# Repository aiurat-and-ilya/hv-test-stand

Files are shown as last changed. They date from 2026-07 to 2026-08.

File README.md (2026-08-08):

# Лабораторный стенд для испытания высоковольтных радиоэлементов (HV Test Stand)

Специализированный лабораторный прибор для проведения комплексных испытаний высоковольтных полупроводниковых компонентов и диэлектрических материалов (измерение токов утечки, определение напряжения пробоя). 

Проект охватывает полный цикл разработки устройства: от проектирования схемы и симуляции физических процессов до конструирования корпуса, подготовки файлов производства и натурных испытаний готового стенда.

Разработчики: **[aiurat](https://github.com/aiurat)** и **[ilyakorni](https://github.com/ilyakorni)**.

---

## 1. Схемотехника и трассировка платы (EasyEDA)

Электронный узел устройства спроектирован в среде **EasyEDA**:
* **Схема:** Импульсный повышающий преобразователь (Boost Converter) на базе ШИМ-контроллера **TL494 (DA2)** и драйвера затвора **IR2302 (DA1)**. Первичное питание осуществляется через интерфейс USB Type-C (**X1**) с триггером быстрой зарядки **CH224K (DD1)**, запрашивающим профиль питания 12 В (до 2 А).
* **Плата:** Двухслойная печатная плата (FR-4) со встроенным планарным радиатором (медными полигонами без паяльной маски) для пассивного охлаждения силового ключа **VT2 (IRF640)**.

<p align="center">
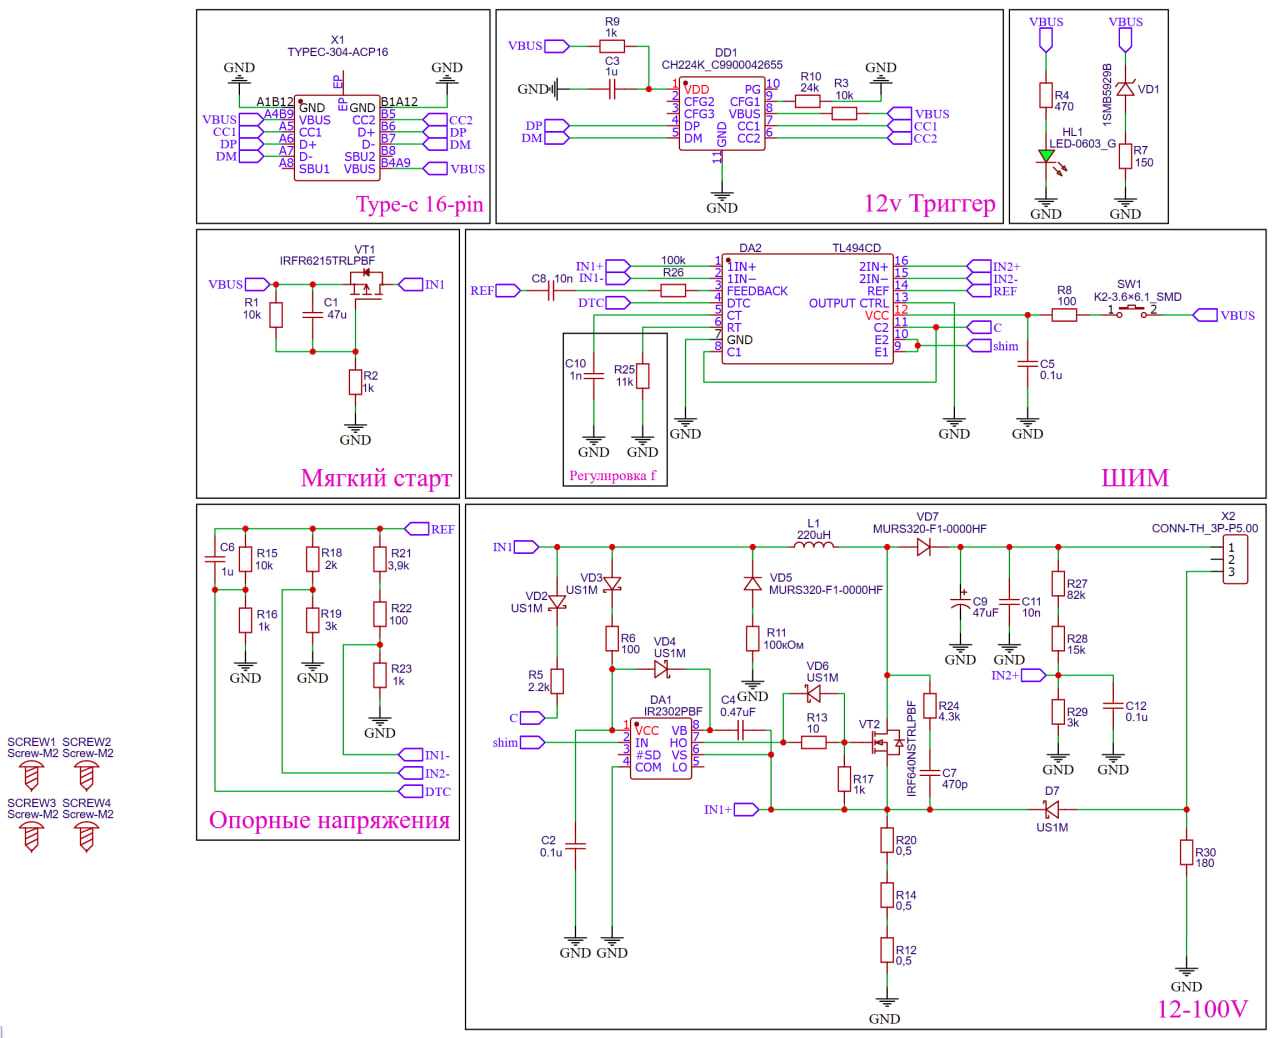
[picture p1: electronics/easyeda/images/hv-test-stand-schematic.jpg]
Принципиальная схема стенда
  
</p>

<p align="center">
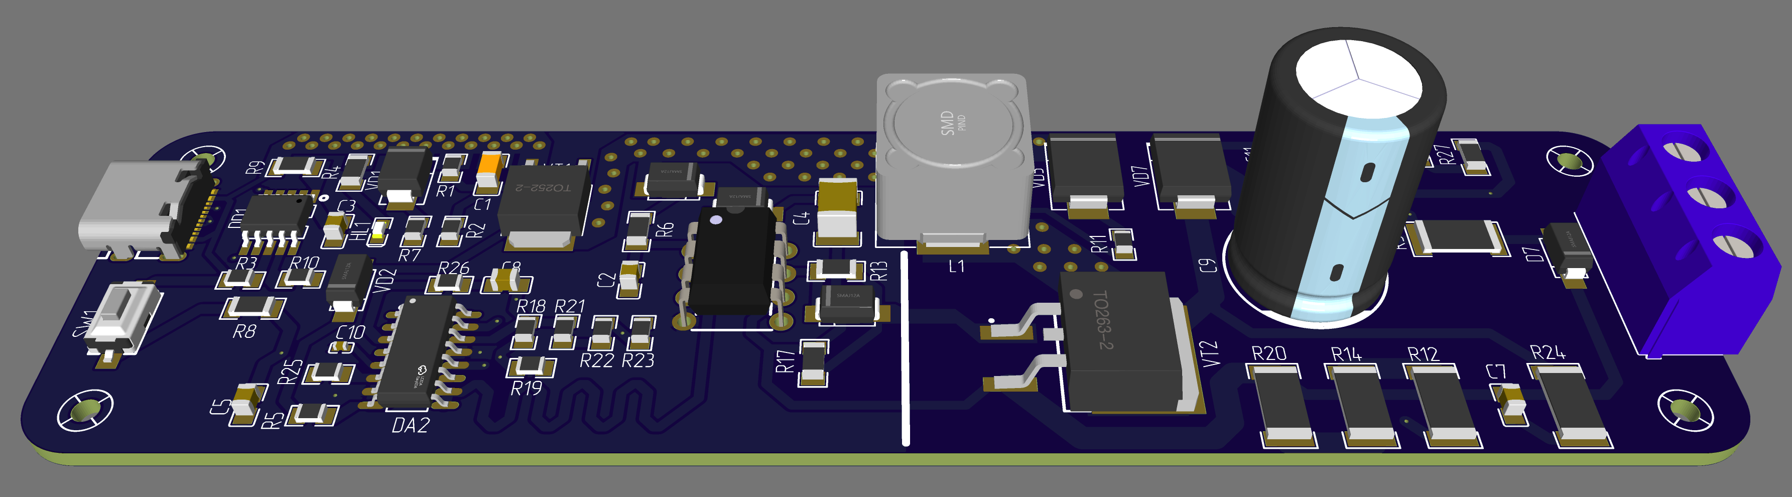
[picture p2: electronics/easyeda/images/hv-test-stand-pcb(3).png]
3D-модель печатной платы
  
</p>

---

## 2. Симуляция физических процессов

Перед отправкой платы в производство было проведено компьютерное моделирование ключевых узлов устройства:

### Тепловое моделирование планарного радиатора (CST Studio Suite)
Для качественной оценки эффективности охлаждающего медного полигона была проведена тепловая симуляция в 3 итерации:
1. **Итерация 1 (Базовая):** Упрощенный расчет на пустом текстолите для оценки векторов распространения тепла.
2. **Итерация 2 (Контрольная):** Моделирование платы с компонентами без физического контакта полигона радиатора с платой в расчетной сетке. Это позволило зафиксировать характерный критический перегрев в одной точке при отсутствии теплоотвода.
3. **Итерация 3 (Финальная):** Тепловой контакт был настроен. Добавлены точки нагрева в зоне без радиатора (3 резистора). Симуляция наглядно подтвердила, что в зоне без радиатора образуется сильный перегрев, тогда как планарный медный полигон успешно распределяет и уводит тепло по плате.

<p align="center">
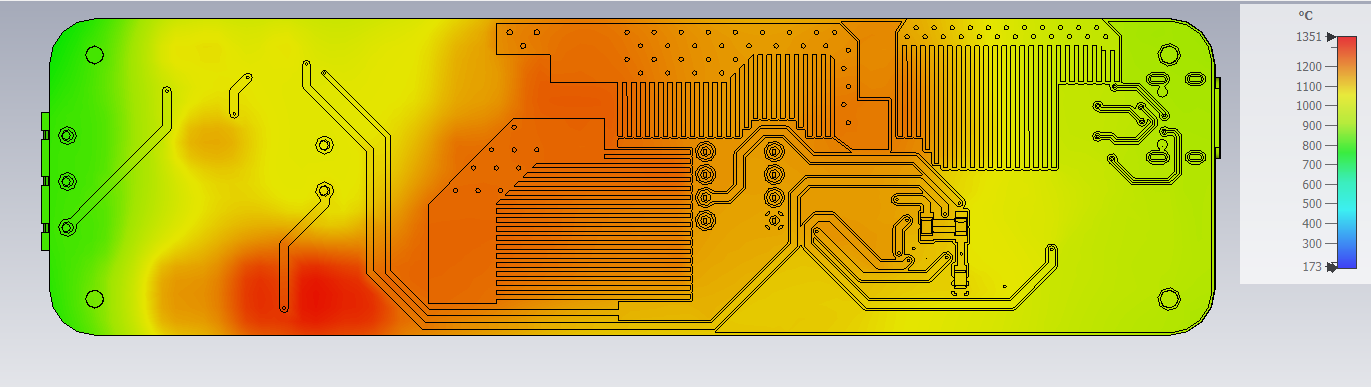
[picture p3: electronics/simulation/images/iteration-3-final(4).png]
Тепловое моделирование в CST Studio Suite
  
</p>

### Моделирование мягкого старта (Micro-Cap)
Проведено моделирование переходных процессов (*Transient Analysis*) узла мягкого старта на транзисторе **VT1**. Моделирование подтвердило плавное нарастание напряжения на нагрузке и ограничение бросков зарядного тока конденсаторов фильтра, что защищает первичный блок питания от перегрузки при старте.

<p align="center">
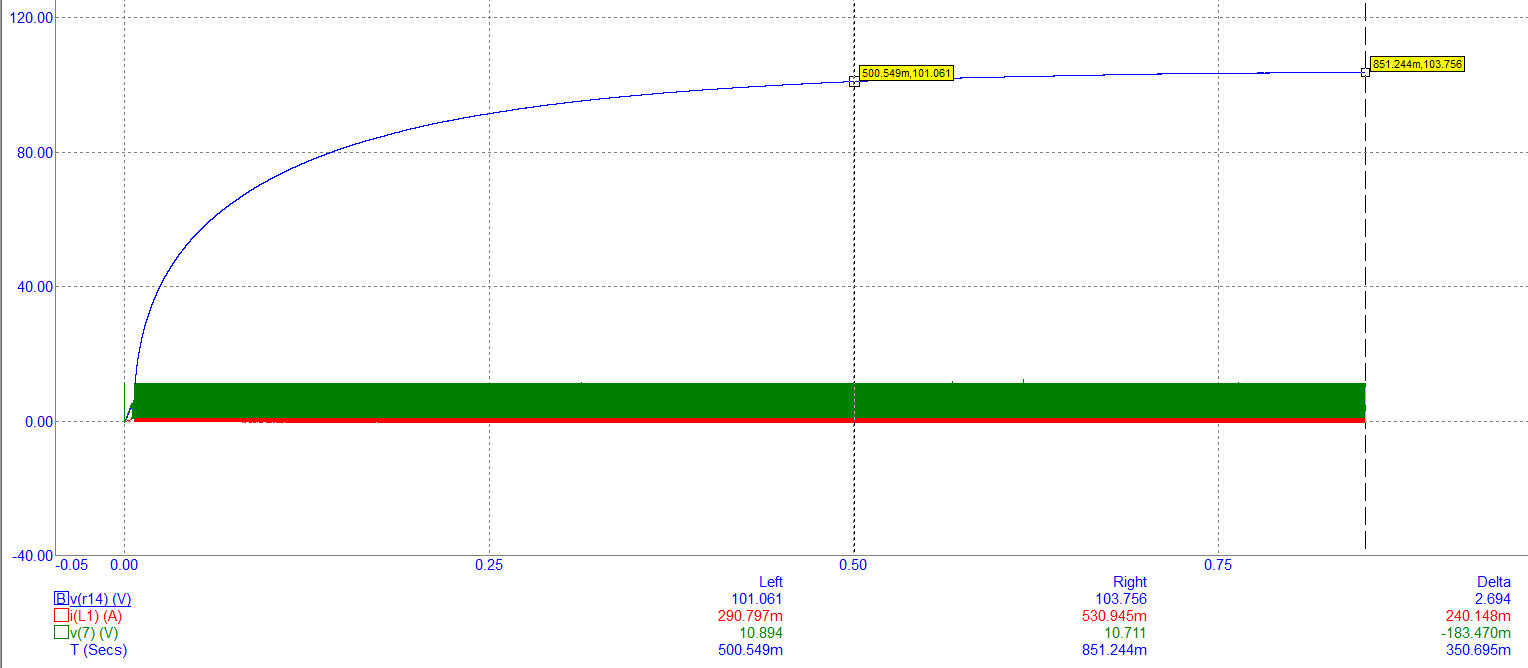
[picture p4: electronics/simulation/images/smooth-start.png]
Симуляция мягкого старта в Micro-Cap
  
</p>

---

## 3. Конструирование корпуса (КОМПАС-3D)

В системе **КОМПАС-3D** спроектирован защитный корпус прибора:
* Конструкция корпуса разделена на отдельные функциональные части (основание, крышка, панели) для удобства 3D-печати.
* В общую механическую сборку (`.a3d`) была импортирована STEP-модель печатной платы (`hv-test-stand-pcb.step`) для контроля соосности разъемов, клемм, кнопок и крепежных отверстий.

---

## 4. Производство и финальные испытания

По подготовленной документации (Gerber-файлы, BOM-таблица, технологическая маршрутная карта) плата была успешно изготовлена, смонтирована и протестирована:
* Проведены замеры выходного напряжения с помощью мультиметра.
* Зафиксирована стабильная работа преобразователя и генерация выходного напряжения **99.6 В** при питании от интерфейса USB-C.

<p align="center">
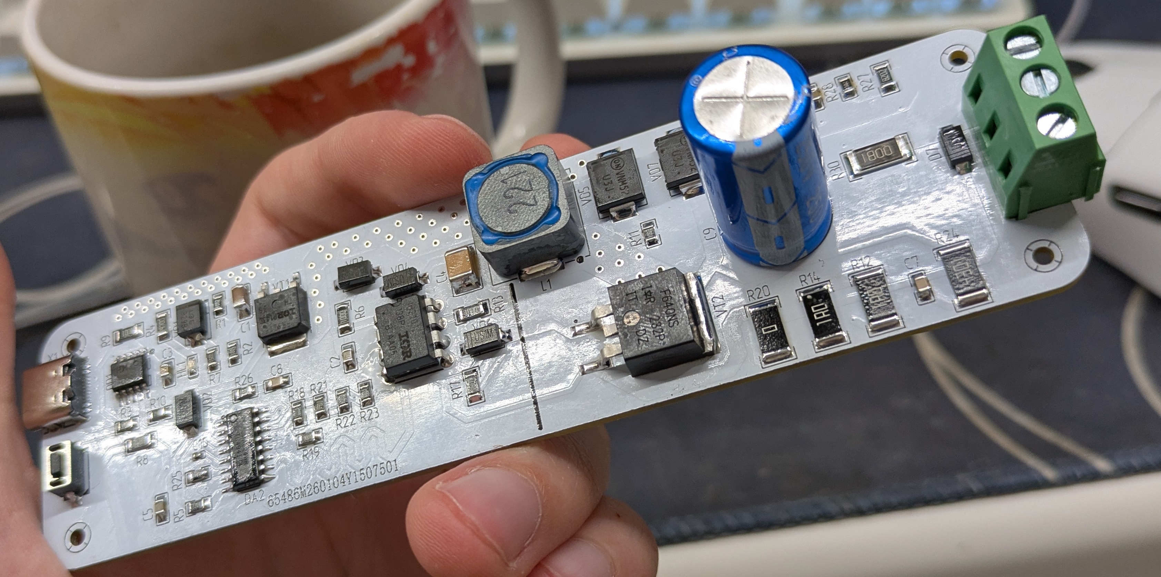
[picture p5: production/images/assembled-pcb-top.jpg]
Собранная плата
  
</p>

<p align="center">
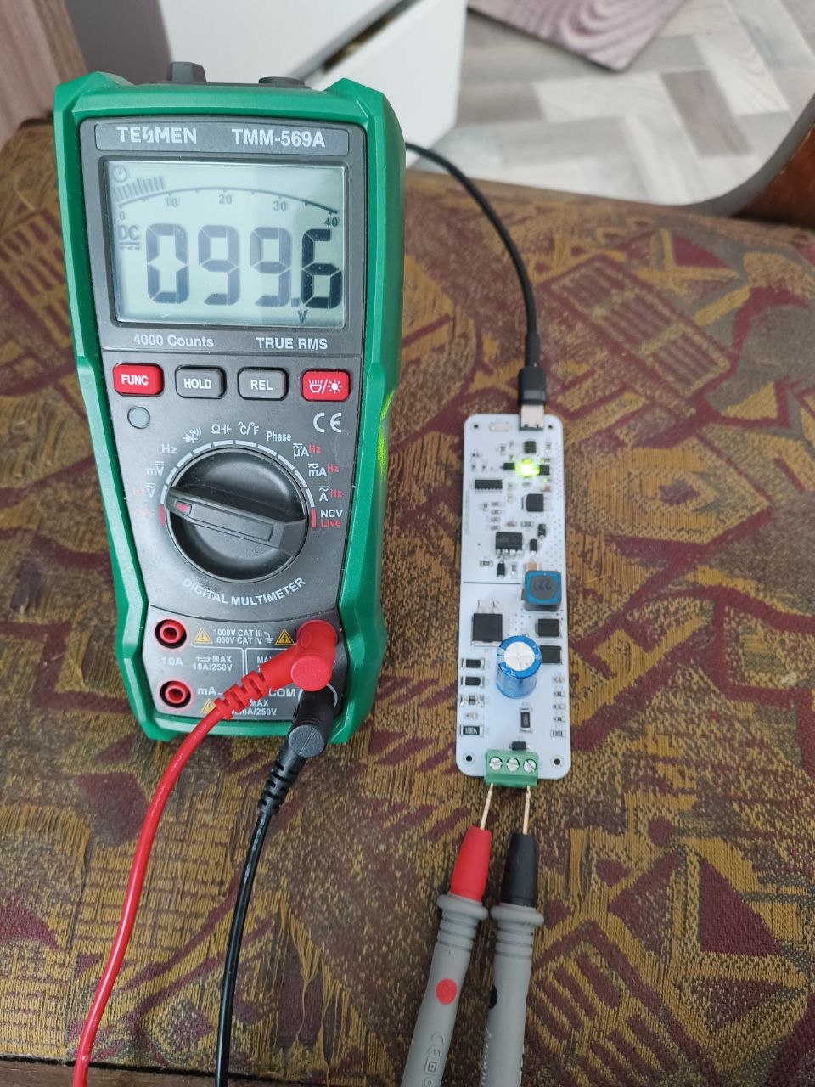
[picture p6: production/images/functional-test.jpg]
Тест выходного напряжения
  
</p>

---

## 5. Навигация по репозиторию

* 🔌 **[Электроника](./electronics/)** — принципиальная схема и печатная плата в EasyEDA.
* 📈 **[Симуляции](./electronics/simulation/)** — подробные отчеты и файлы тепловых расчетов (CST) и мягкого старта (Micro-Cap).
* ⚙️ **[Механика](./mechanical/)** — 3D-модели корпуса (КОМПАС-3D) и STEP-файл платы.
* 🛠️ **[Производство](./production/)** — Gerber-файлы, чертежи PDF, спецификация (BOM) со ссылками и фотографии готового прибора.
* 📄 **[Документация](./docs/)** — подробное [описание работы схемы](./docs/README.md).

## Лицензия

Copyright (c) 2026 Айрат Ялалетдинов, Илья Корнилов

Этот исходный документ описывает открытое аппаратное обеспечение (Open Hardware) и распространяется под лицензией CERN-OHL-P v2. 
Вы можете распространять и изменять этот исходный документ, а также производить на его основе продукты в соответствии с 
условиями лицензии CERN-OHL-P v2 (https://cern.ch/cern-ohl).

Этот исходный документ распространяется БЕЗ КАКИХ-ЛИБО ЯВНЫХ ИЛИ ПОДРАЗУМЕВАЕМЫХ ГАРАНТИЙ, 
ВКЛЮЧАЯ ГАРАНТИИ ТОВАРНОЙ ПРИГОДНОСТИ, УДОВЛЕТВОРИТЕЛЬНОГО КАЧЕСТВА ИЛИ СООТВЕТСТВИЯ 
КОНКРЕТНЫМ ЦЕЛЯМ. Пожалуйста, ознакомьтесь с условиями CERN-OHL-P v2 для получения подробной информации.

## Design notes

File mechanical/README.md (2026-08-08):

# Механическая часть (КОМПАС-3D)

В этом разделе находятся файлы конструкции корпуса прибора, разработанные в системе **КОМПАС-3D**.

### Структура папки:

* 📁 **[enclosure](./enclosure/)** — исходные 3D-модели:
  * Общая сборка корпуса (`.a3d`).
  * Детали корпуса для печати/изготовления (`.m3d`).
  * Фурнитура (модели винтов, тактовых кнопок).
* 📁 **[images](./images/)** — скриншоты готовых 3D-моделей и деталей корпуса.
* 📁 **[drawings](./drawings/)** — чертежи деталей и сборочные единицы в формате `.cdw`.
* 📄 **[pcb.step](./pcb.step)** — 3D-модель печатной платы (STEP), импортированная для сопряжения и контроля зазоров в общей сборке.

---

## 3D-визуализация корпуса прибора

<p align="center">
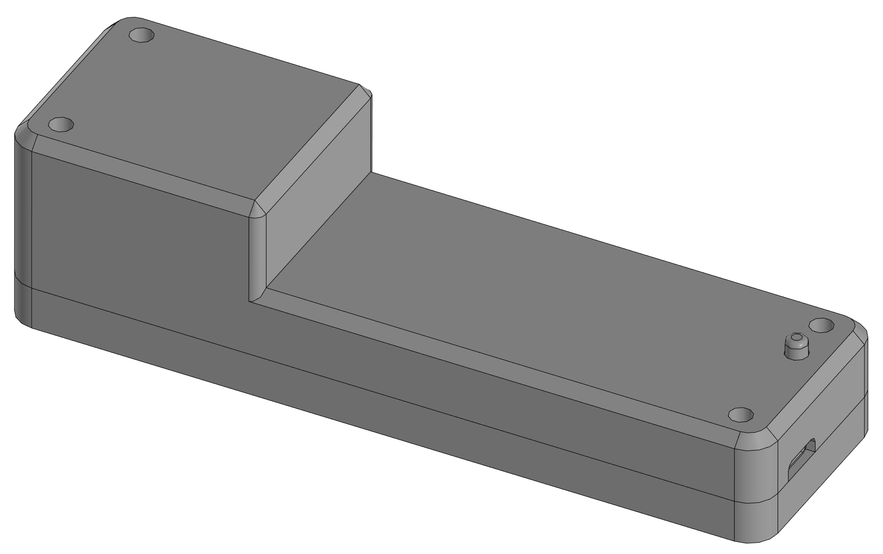
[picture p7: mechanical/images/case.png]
Общая сборка корпуса стенда
  
  <br/><br/>
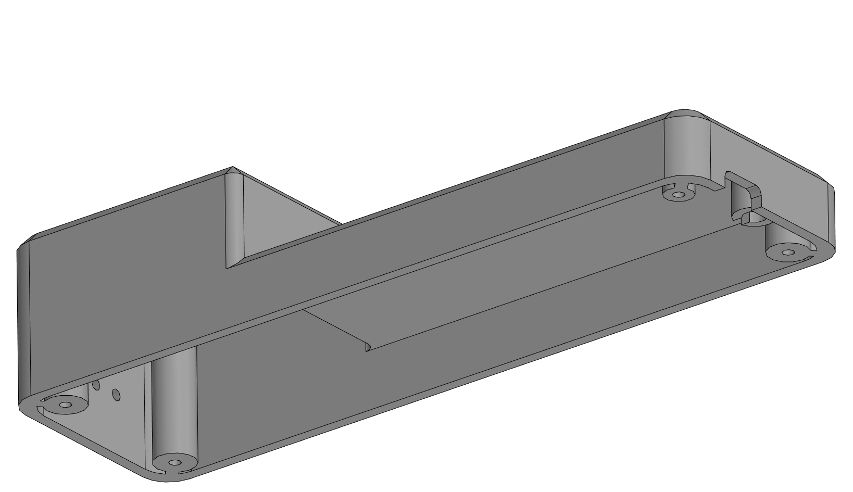
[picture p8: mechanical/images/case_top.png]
Верхняя крышка корпуса (Top Cover)
  
  <br/><br/>
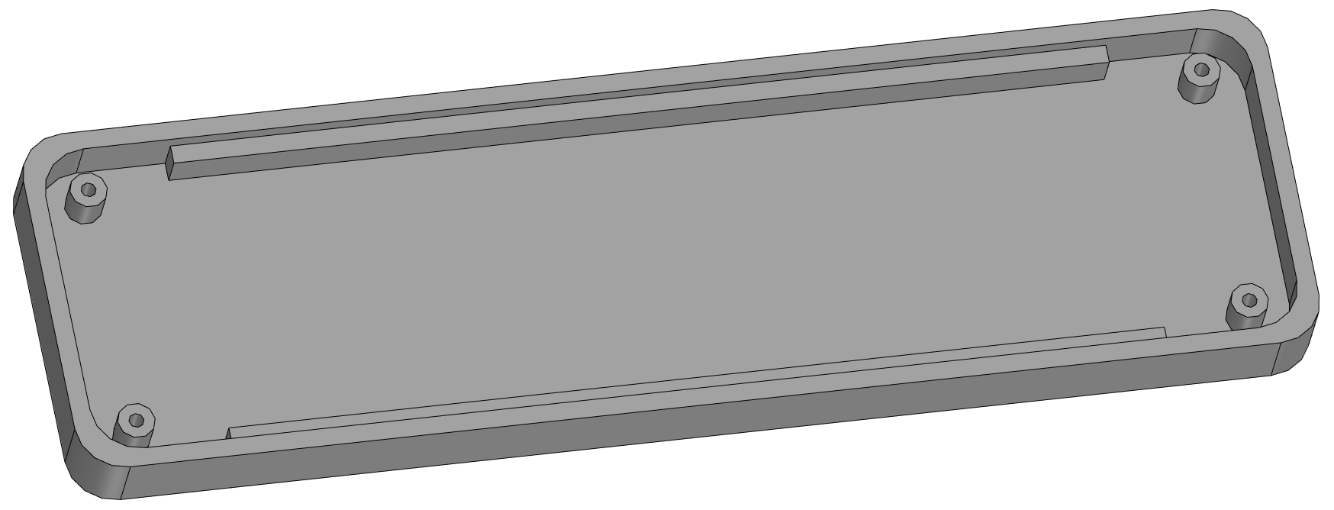
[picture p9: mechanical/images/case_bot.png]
Основание корпуса (Bottom Base)
  
</p>

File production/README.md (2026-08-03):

# Файлы для производства (Production)

В этом разделе собраны финальные файлы, необходимые для заказа печатной платы, закупки компонентов и сборки устройства.

### Содержимое папки:

* 📁 **[gerber](./gerber/)** — Gerber-файлы (проект платы, подготовленный для отправки на производство).
* 📁 **[drawings](./drawings/)** — сборочные и габаритные чертежи деталей в формате `PDF` для быстрого просмотра и печати.
* 📁 **[images](./images/)** — фотографии изготовленной платы (без компонентов и в сборе), а также тест замера выходного напряжения.
* 📄 **[bom.xlsx](./bom.xlsx)** — перечень элементов (BOM) со спецификациями и ссылками на компоненты в магазине «Чип и Дип» *(примечание: некоторые внешние ссылки со временем могли стать неактуальными)*.

---

## Фотографии изготовленной печатной платы и тестирования

### 1. Печатная плата без компонентов
<p align="center">
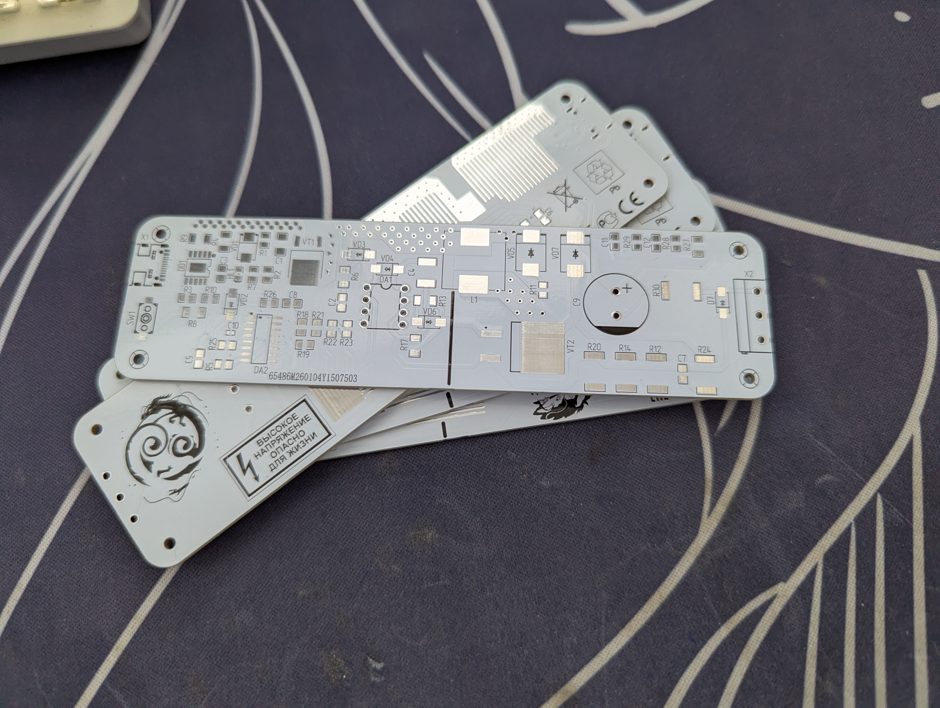
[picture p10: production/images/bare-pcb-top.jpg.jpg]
Голая печатная плата - Вид сверху
  
  <br/><br/>
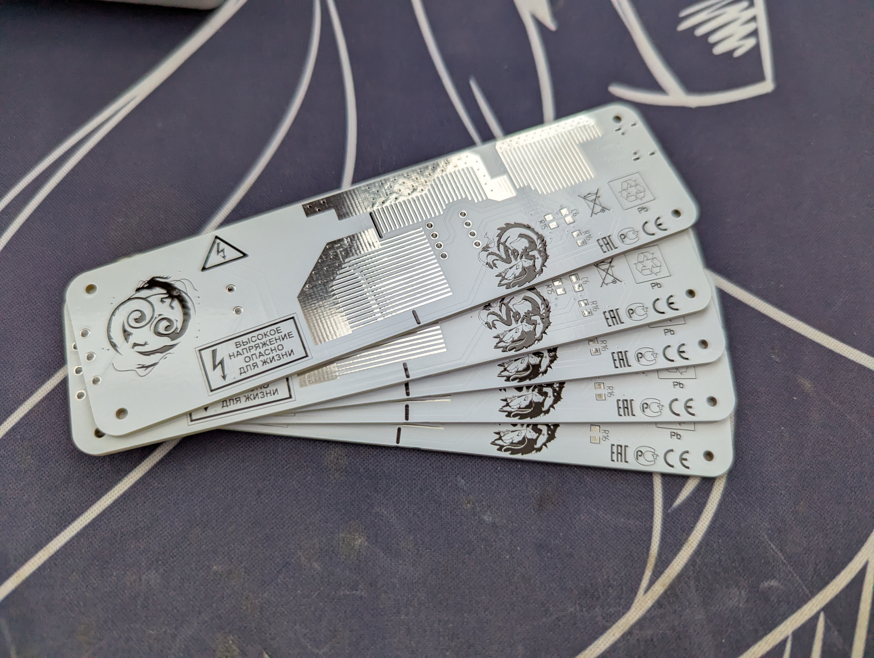
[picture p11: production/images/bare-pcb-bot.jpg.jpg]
Голая печатная плата - Вид снизу
  
</p>

---

### 2. Печатная плата в сборе
<p align="center">
  Смонтированная печатная плата - Вид сверху
  <br/><br/>
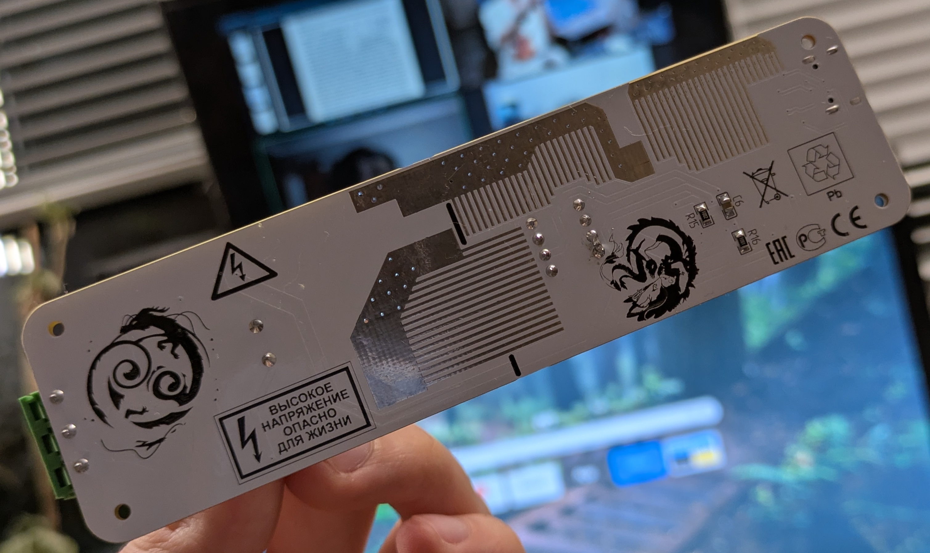
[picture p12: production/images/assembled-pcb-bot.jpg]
Смонтированная печатная плата - Вид снизу
  
</p>

---

### 3. Функциональный тест
<p align="center">
  Проверка выходного напряжения преобразователя
</p>

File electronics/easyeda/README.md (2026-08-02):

# Проектирование схемы и печатной платы (EasyEDA)

Разработка электрической принципиальной схемы и топологии печатной платы (PCB) лабораторного стенда выполнена в среде проектирования **EasyEDA**. 

В данном подразделе представлены графические материалы проекта: принципиальная схема, а также двухмерная и трехмерная визуализация печатной платы.

---

## 1. Схема электрическая принципиальная

Схема разработана с учетом требований к компоновке импульсных повышающих преобразователей. Логические цепи управления (ШИМ-контроллер TL494, драйвер IR2302) развязаны и защищены от помех со стороны силовой части.

<p align="center">
  Принципиальная схема стенда
</p>

---

## 2. Топология печатной платы (2D-вид)

Печатная плата выполнена на двухслойном фольгированном стеклотекстолите (FR-4). Трассировка силовых дорожек сделана максимально широкой для минимизации сопротивления и нагрева. Также на плате сформированы свободные от паяльной маски медные полигоны, выполняющие роль планарного радиатора для пассивного охлаждения силовых элементов.

*Ниже представлены скриншоты проводящего рисунка платы без установленных компонентов (верхний и нижний слои):*

<p align="center">
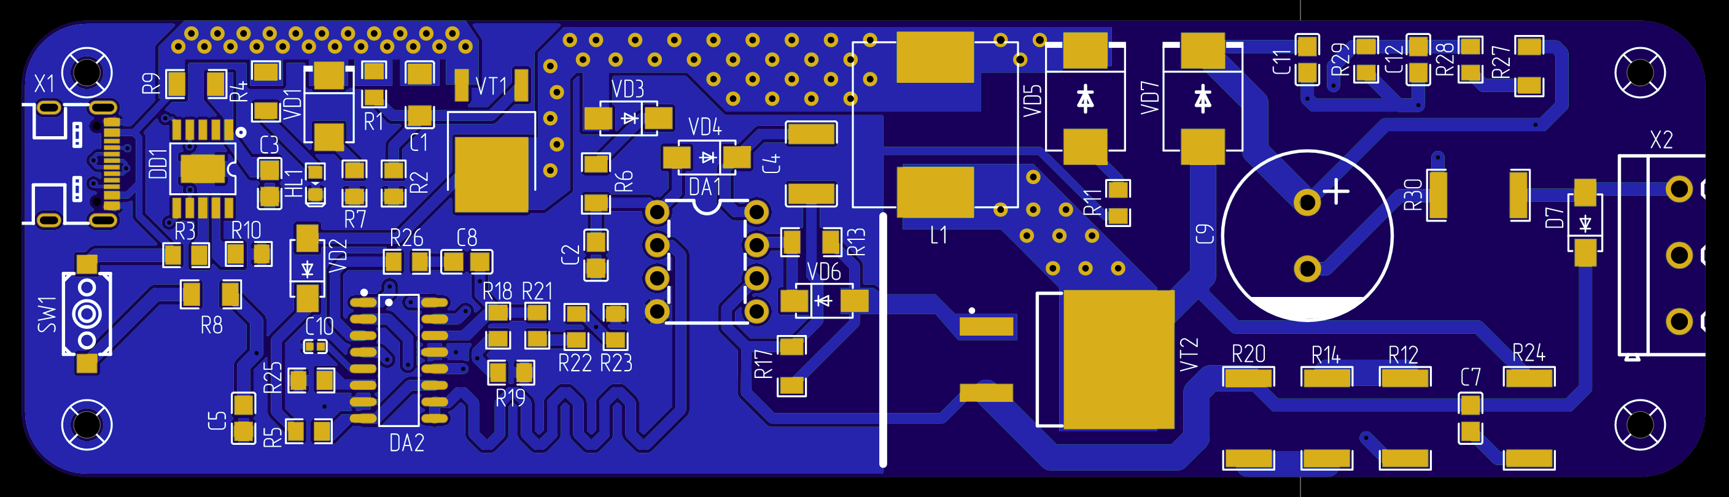
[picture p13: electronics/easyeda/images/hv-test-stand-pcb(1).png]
Топология печатной платы - Верхний слой (Top Layer)
  
  <br/><br/>
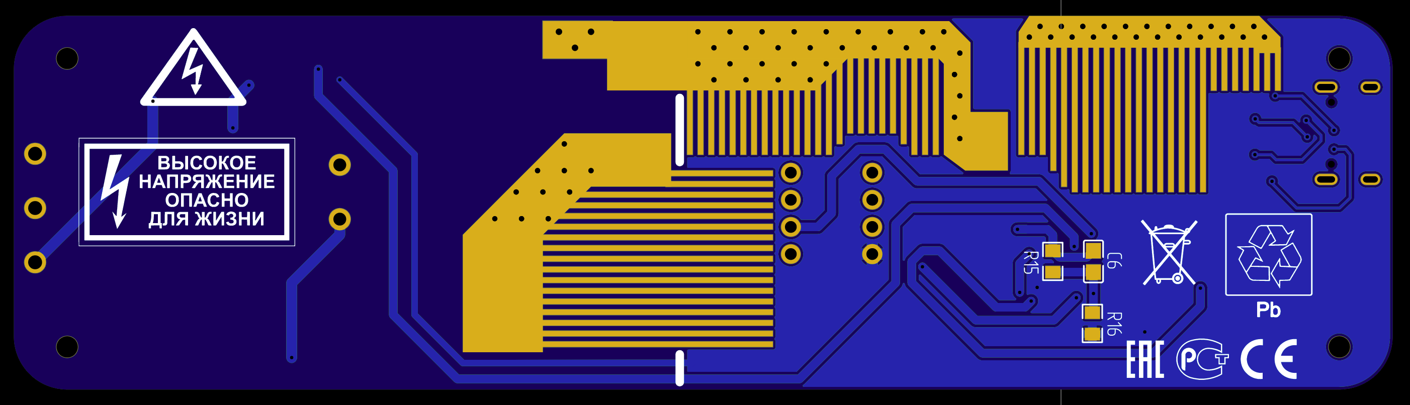
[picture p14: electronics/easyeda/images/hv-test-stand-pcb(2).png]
Топология печатной платы - Нижний слой (Bottom Layer)
  
</p>

---

## 3. Трехмерная визуализация платы (3D-вид)

Для проверки механической совместимости компонентов и оценки плотности компоновки элементов была построена трехмерная модель печатной платы в сборе с корпусами радиодеталей.

*Ниже представлены 3D-рендеры готовой платы (с установленными компонентами):*

<p align="center">
  3D-визуализация платы - Вид сверху
  <br/><br/>
  3D-визуализация платы - Вид снизу
</p>

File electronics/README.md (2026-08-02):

# Электроника (Electronics)

Схемотехника, трассировка печатной платы в **EasyEDA** и симуляция физических процессов прибора.

### Структура папки:

* 📁 **[easyeda](./easyeda/)** — исходные файлы схемы и платы в формате проекта EasyEDA.
* 📁 **[simulation](./simulation/)** — тепловой анализ планарного радиатора в CST Studio Suite и симуляция переходных процессов в Micro-Cap.

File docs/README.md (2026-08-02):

# Описание работы электрической принципиальной схемы стенда

Разработанное устройство представляет собой специализированный лабораторный стенд, предназначенный для проведения комплексных испытаний высоковольтных полупроводниковых компонентов и материалов. 

### Основные инженерно-технические задачи стенда:
* **Измерение токов утечки** (обратных токов) радиоэлементов при воздействии высоких напряжений с использованием внешнего измерительного прибора (микроамперметра).
* **Проверка диэлектрической прочности** и определение напряжения пробоя активных и пассивных компонентов.
* **Обеспечение питанием маломощных узлов** и приборов, требующих для работы высокого потенциала.

Устройство выполнено на базе импульсного повышающего преобразователя напряжения с развитой системой обратных связей по току и напряжению, что обеспечивает стабильность выходных характеристик и безопасность эксплуатации.

---

## 1. Входной узел и система питания

Питание стенда осуществляется через современный интерфейс USB Type-C (разъем **X1**). 

* **Контроллер-триггер DD1 (CH224K):** Введен в схему для реализации возможности получения повышенной мощности от современных зарядных устройств. Данная микросхема поддерживает протоколы быстрой зарядки, такие как *USB Power Delivery (PD)* и *Quick Charge (QC)*. Использование контроллера **DD1** позволяет согласовать с источником питания выходное напряжение **12 В при токе до 2 А**, что значительно расширяет энергетический бюджет устройства по сравнению со стандартными 5 В.
* **Стабилитрон VD1 и резистор R7:** Установлены в цепи питания для защиты низковольтной логической части от случайных скачков напряжения. Резистор **R7** стабилизирует рабочую точку стабилитрона.
* **Светодиодный индикатор HL1:** Обеспечивает визуальный контроль подачи первичного напряжения. Включен через токоограничивающий резистор **R4**.

---

## 2. Узел мягкого старта и безопасность

Важной особенностью конструкции является наличие системы «мягкого старта» первичных цепей и аппаратного контроля безопасности.

* **Система «мягкого старта» на полевом транзисторе VT1:**
  * **Принцип работы:** При подаче питания цепи смещения в затворе **VT1** обеспечивают постепенное открытие канала сток-исток. Плавное изменение поперечного сечения канала приводит к постепенному снижению сопротивления участка цепи, что ограничивает производную тока и исключает броски тока при зарядке емкостей фильтра.
* **Тактовая кнопка SW1:** Включение высоковольтной части устройства жестко привязано к нажатию кнопки **SW1**. Это исключает наличие высокого потенциала на выходных клеммах **X2** в режиме ожидания, обеспечивая безопасность оператора.

---

## 3. ШИМ-управление на базе TL494

Центральным управляющим звеном преобразователя является специализированная микросхема **DA2 (TL494)** — классический двухтактный ШИМ-контроллер, работающий в данном случае в схеме однотактного управления силовым ключом.

### Функциональная обвязка TL494:

1. **Цепь задания частоты:** Резистор **R25** и конденсатор **C10** определяют частоту встроенного осциллятора, задавая тем самым стабильную частоту коммутации силового ключа.
2. **Регулировка мертвого времени (DTC):** Элементы **R15**, **R16**, **C6**, подключенные к выводу *DTC (Dead Time Control)*, реализуют дополнительный уровень мягкого запуска непосредственно для ШИМ-сигнала, предотвращая резкие выбросы напряжения при старте генерации.
3. **Система обратных связей:**
   * **Контур стабилизации напряжения:** Делитель на прецизионных резисторах **R27**, **R28**, **R29** снимает сигнал с выхода устройства и подает его на встроенный усилитель ошибки **DA2** (через опорные цепи **R18**, **R19**), непрерывно поддерживая заданный уровень выходного напряжения.
   * **Контур защиты по току:** Группа низкоомных шунтов **R12**, **R14**, **R20** в истоковой цепи силового ключа и опорная сеть **R21**, **R22**, **R23** обеспечивают мониторинг мгновенного тока через транзистор.
   * **Защита от короткого замыкания:** Цепь **R30**, **VD8** обеспечивает дополнительный контроль выходного тока, предохраняя устройство от выхода из строя при аварийных режимах (КЗ) на выходных клеммах **X2**.

---

## 4. Силовой каскад и драйвер ключа

* **Драйвер затвора DA1 (IR2302PBF):** Применен для эффективного управления мощным полевым транзистором. Данная микросхема обеспечивает необходимый импульсный ток для быстрой зарядки и разрядки входной емкости затвора силового транзистора **VT2**. Это критически важно для минимизации динамических потерь на ключе и предотвращения работы транзистора в линейном (активном) режиме, сопровождающемся чрезмерным тепловыделением.
* **Силовой ключ VT2 (IRF640):** Мощный МОП-транзистор (MOSFET), обладающий высокой мощностью рассеивания и достаточным напряжением сток-исток для обеспечения стабильной и надежной работы повышающего преобразователя.

### Элементы оптимизации силовой цепи:
* **Дроссель L1:** Является основным накопителем энергии преобразователя. В фазе открытого состояния ключа **VT2** энергия запасается в магнитном поле индуктивности.
* **Снабберная цепь R24, C7:** Образуют RC-снаббер, включенный параллельно силовому ключу. Он поглощает энергию паразитных колебаний и подавляет высокочастотные гармоники («звон»), возникающие в моменты коммутации индуктивности дросселя.
* **Цепь разрядки L1 (VD5, R11):** Диод **VD5** и резистор **R11** способствуют контролируемой разрядке накопленной энергии в моменты закрытия ключа, защищая компоненты схемы от высоковольтного пробоя импульсами самоиндукции.

---

## 5. Выпрямление и фильтрация выходного напряжения

На выходе преобразователя установлен быстродействующий высокочастотный диод **VD7**, выполняющий функцию выпрямления импульсного напряжения. 

Для получения чистого постоянного напряжения на клеммах применяется комбинированная многоступенчатая система фильтрации:
* **Электролитический конденсатор C9:** Обладает большой емкостью и предназначен для эффективного сглаживания низкочастотных пульсаций напряжения.
* **Керамический конденсатор C11:** Благодаря сверхнизкой собственной индуктивности (*ESL*), эффективно подавляет высокочастотные помехи и импульсные всплески в цепи, с которыми физически не справляется электролитический конденсатор.
* **Конденсатор фильтрации измерительной цепи C12:** Обеспечивает финальную фильтрацию в цепи измерения, стабилизируя показания тока и напряжения при подключении внешнего микроамперметра к контакту 2 разъема **X2**.

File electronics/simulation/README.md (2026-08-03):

# Моделирование и симуляция физических процессов

В данном разделе представлены результаты теплового моделирования охлаждающей способности планарного радиатора в среде **CST Studio Suite**, а также схемотехнического анализа узла мягкого старта в программе **Micro-Cap**.

---

## 1. Тепловой анализ планарного радиатора (CST Studio Suite)

**Цель исследования:** Качественная оценка эффективности работы планарного радиатора (медного полигона печатной платы) и визуализация путей распределения тепла по плате.

*Примечание: Так как точные значения тепловыделения реальных компонентов на этапе проектирования могут варьироваться, тепловая мощность в моделях задавалась с избыточным запасом. Абсолютные значения температур в симуляциях носят номинальный характер и служат для демонстрации градиентов теплоотвода.*

### Итерация 1: Упрощенная базовая модель
На первом этапе была подготовлена упрощенная модель, состоящая только из текстолитового основания и медных проводников, без учета корпусов радиокомпонентов.
* **Методика:** В качестве источника тепла в CST Studio Suite был создан условный твердотельный объект (кубик), расположенный непосредственно в зоне планарного радиатора.
* **Результат:** Зафиксирован нагрев в самой горячей точке до **41.3 °C**. Модель позволила оценить базовые направления растекания тепла.
* **Выявленные недостатки:** Для реалистичного анализа необходимо использовать полную 3D-сборку платы с компонентами и задать несколько распределенных точек нагрева.

<p align="center">
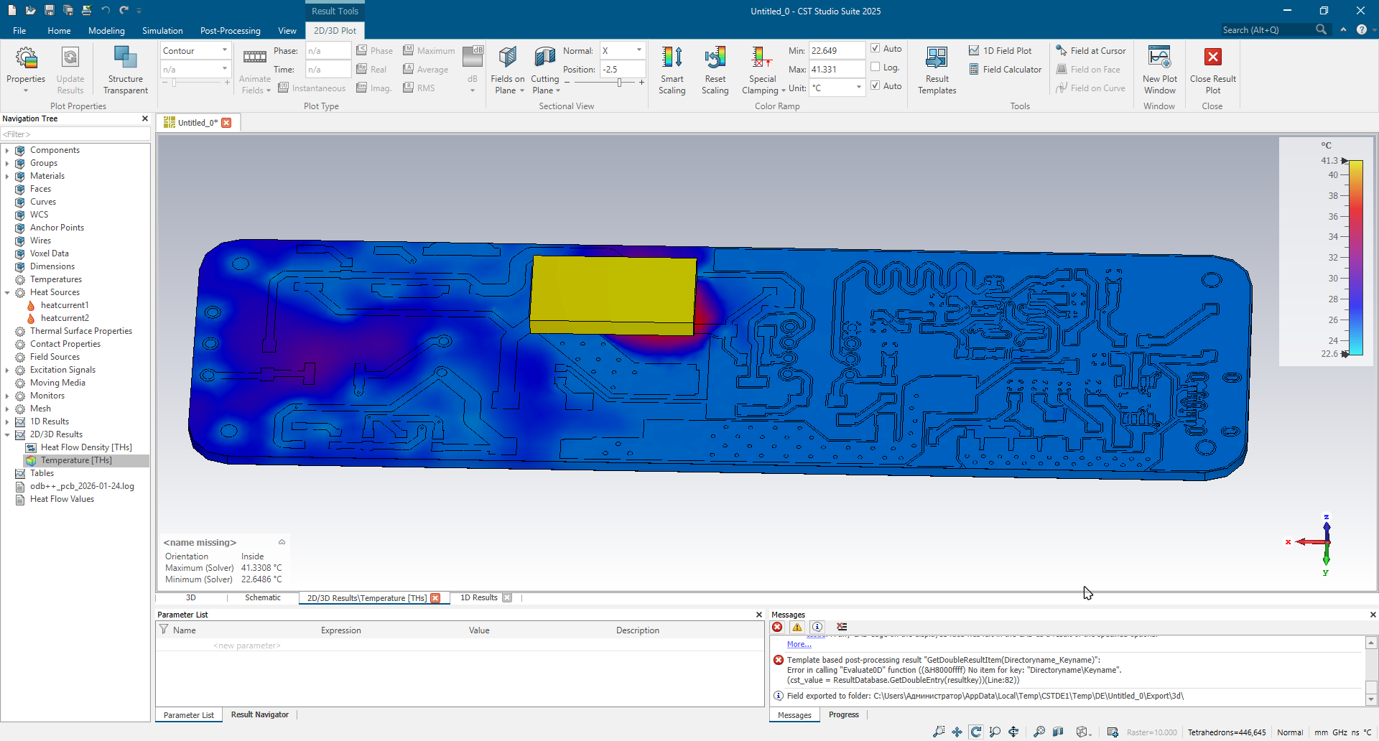
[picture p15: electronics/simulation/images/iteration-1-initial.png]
Итерация 1 - Базовая модель
  
</p>

---

### Итерация 2: Модель с компонентами (без теплового контакта)
На этом этапе была задействована детализированная 3D-модель платы со всеми установленными радиоэлементами.
* **Методика:** Выделены 3 характерные точки нагрева на корпусах компонентов, расположенных в зоне планарного радиатора. На них была подана тепловая нагрузка.
* **Результат:** Зафиксирован сильный локальный перегрев (пиковое значение **590 °C**) из-за завышенной мощности источников.
* **Выявленные особенности и дефекты:** 
  При анализе модели обнаружилось, что медный полигон радиатора и подложка печатной платы физически не соприкасались в расчетной сетке. Данная ошибка позволила использовать итерацию в качестве «контрольной группы»: на тепловой карте отчетливо видно, как тепло концентрируется исключительно в точках нагрева и не уходит в плату из-за отсутствия теплового контакта.
* **План действий:** Обеспечить корректное механическое и тепловое сопряжение проводников с платой для сравнения результатов.

<p align="center">
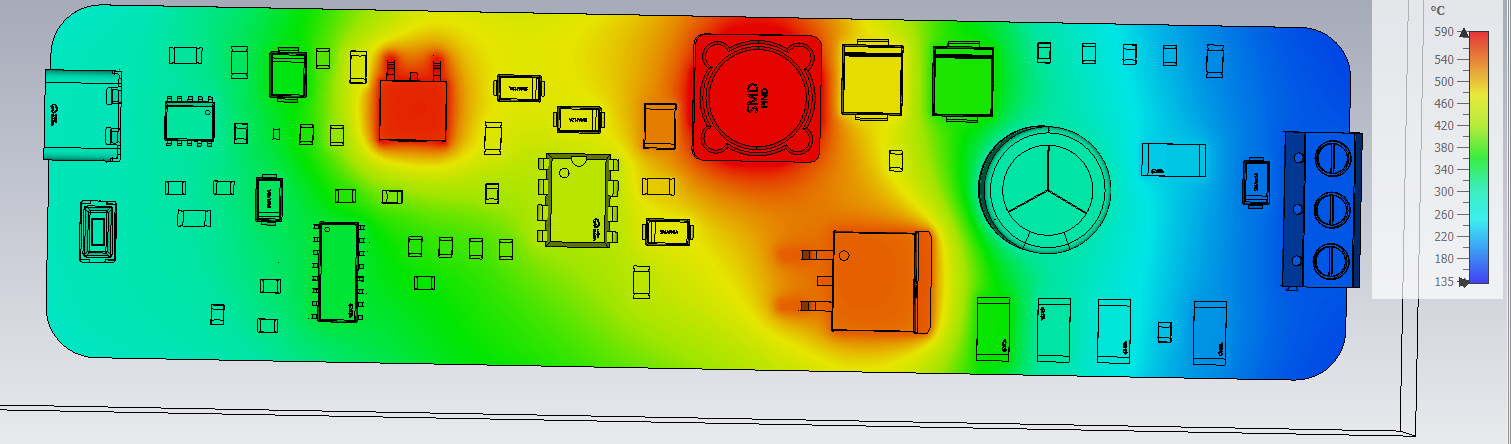
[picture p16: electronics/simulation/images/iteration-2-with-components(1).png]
Итерация 2 - Общий вид
  
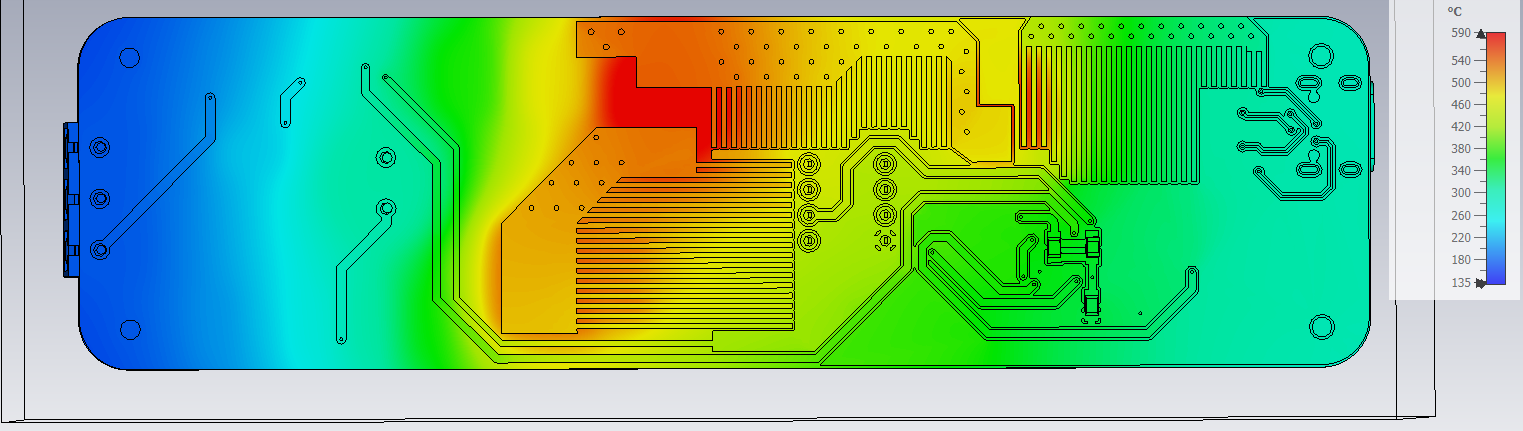
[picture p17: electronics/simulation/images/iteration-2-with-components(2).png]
Итерация 2 - Тепловая карта
  
</p>

---

### Итерация 3: Финальная модель (с тепловым контактом)
В финальной версии модели были устранены все геометрические несоответствия и добавлены дополнительные тепловые источники для сравнительного анализа.
* **Методика:** 
  * Настроено корректное сопряжение (тепловой контакт) радиаторов с поверхностью печатной платы.
  * Добавлены новые точки нагрева, в том числе в области платы, где планарный радиатор отсутствует (группа из 3 рядом стоящих резисторов).
* **Результат:** 
  Из-за улучшения теплопередачи и добавления источников пиковая температура на модели составила **1351 °C** (номинальное значение). Симуляция наглядно продемонстрировала разницу процессов:
  * В зоне трех резисторов (без радиатора) наблюдается критическая локальная точка перегрева с резким градиентом.
  * В зонах компонентов, сопряженных с медными полигонами, тепло эффективно распределяется по площади радиатора и рассеивается в объеме платы.
* **Вывод:** Тестовое моделирование завершено, работоспособность и высокая эффективность планарного радиатора успешно подтверждены качественным анализом.

#### Тепловые карты проводящего рисунка (медных слоев):
<p align="center">
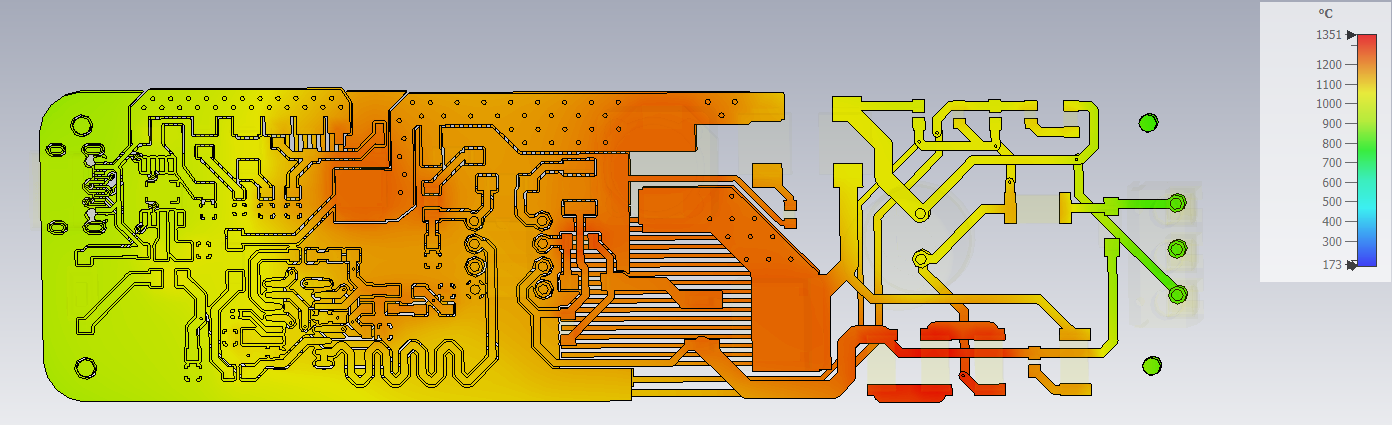
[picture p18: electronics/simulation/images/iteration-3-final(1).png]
Итерация 3 - Медные слои 1
  
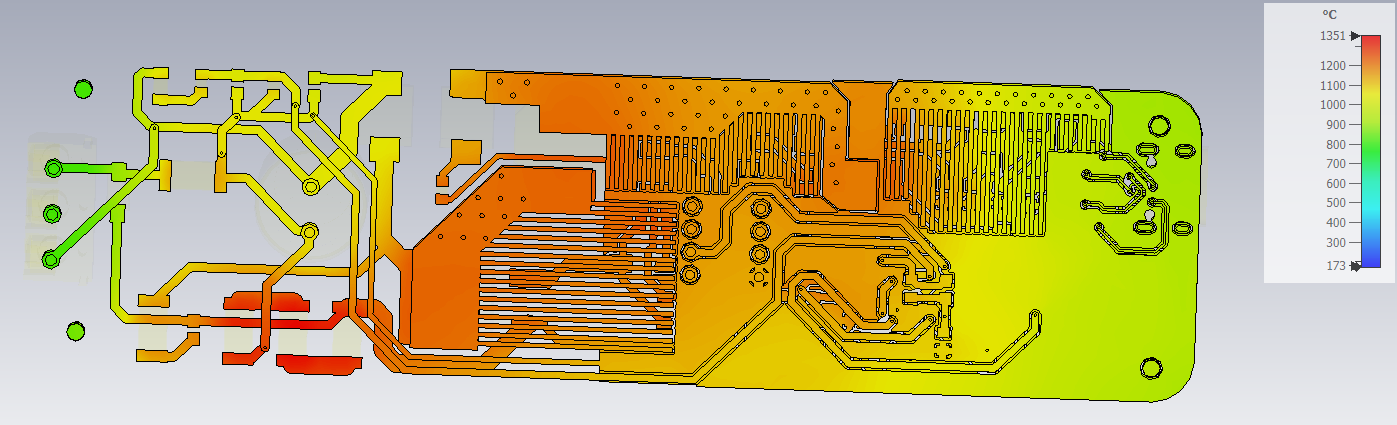
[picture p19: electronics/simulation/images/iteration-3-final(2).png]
Итерация 3 - Медные слои 2
  
</p>

#### Тепловые карты всей платы в сборе:
<p align="center">
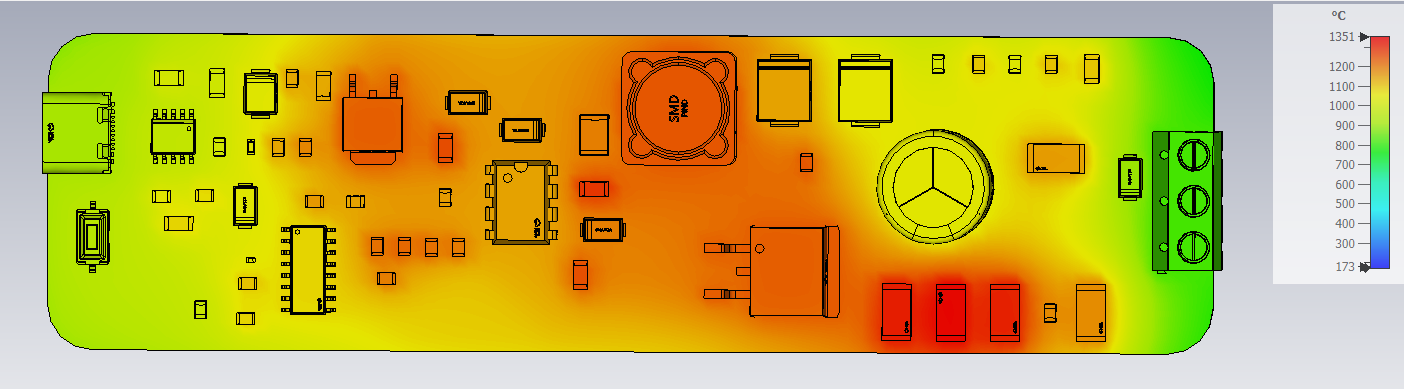
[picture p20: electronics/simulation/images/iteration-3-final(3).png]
Итерация 3 - Сборка платы 1
  
  Итерация 3 - Сборка платы 2
</p>

---

## 2. Схемотехническое моделирование мягкого старта (Micro-Cap)

Для проверки работоспособности узла плавного пуска первичных цепей питания было проведено моделирование переходных процессов (*Transient Analysis*) в среде **Micro-Cap**.

* **Результат симуляции:** На графике переходного процесса отчетливо видны плавное нарастание напряжения на нагрузке и ограничение пикового зарядного тока емкостей до безопасных значений. Схема полностью подтвердила свою расчетную эффективность.

<p align="center">
  Симуляция мягкого старта в Micro-Cap
</p>

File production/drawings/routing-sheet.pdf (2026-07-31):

ПРИЛОЖЕНИЕ 3

Дубл
Взам.
Подп.

Комплект документов
на технологический процесс сборки и монтажа «Стенд для диагностики полупроводниковых радиоэлементов»
ТЛ | Титульный лист

ПРИЛОЖЕНИЕ | ГОСТ 3.1123 – 84 Форма 7
Дубл
Взам
Подл | изм | лист | № докум | подпись | дата | изм | лист | № докум | подпись | дата
| | Листов 4 | Лист 1

Разраб
проверил
Т. Контр
ГТПП
Н. контр
К/М | Цех | Уч | РМ | Опер | Поз | Наименование ДСЕ или материала | Обозначение ДСЕ | ОПП | ЕВ | ЕН | КИ | Н.расх
Я | | | | | | | | | | Раз.п Общ.п | | Такт п.
| | 030 | | | 01 Плата | | ПК51.741424.001 | | шт. | 1 | | 1
| Резисторы
010,015,020,030 | 02 0,125 Вт 0805 10 кОм, 1% | R1 | шт. | 1 | 1
010,015,020,030 | 03 0,125 Вт 0805 1 кОм, 1% | R2 | шт. | 1 | 1
010,015,020,030 | 04 0,125 Вт 0805 10 кОм, 1% | R3 | шт. | 1 | 1
010,015,020,030 | 05 0,25 Вт 1206 470 Ом, 1% | R4 | шт. | 1 | 1
010,015,020,030 | 06 0,125 Вт 0805 2,2 кОм, 1% | R5 | шт. | 1 | 1
010,015,020,030 | 07 0,25 Вт 1206 100 Ом, 1% | R6 | шт. | 1 | 1
010,015,020,030 | 08 0,125 Вт 0805 150 Ом, 1% | R7 | шт. | 1 | 1
010,015,020,030 | 09 0,25 Вт 1206 100 Ом, 1% | R8 | шт. | 1 | 1
010,015,020,030 | 10 0,25 Вт 1206 1 кОм, 1% | R9 | шт. | 1 | 1
010,015,020,030 | 11 0,125 Вт 0805 24 кОм, 1% | R10 | шт. | 1 | 1
010,015,020,030 | 12 0,125 Вт 0805 100 кОм, 1% | R11 | шт. | 1 | 1
КК | КОМПЛЕКТОВОЧНАЯ КАРТА

ПРИЛОЖЕНИЕ | ГОСТ 3.1123 – 84 Форма 7
Дубл
Взам
Подл | изм | лист | №докум | подпись | дата | изм | лист | №докум | подпись | дата
| | Листов 4 | Лист 2

Разраб
проверил
Т. Контр
ГТПП
Н. контр
К/М | Цех | Уч | РМ | Опер | Поз | Наименование ДСЕ или материала | Обозначение ДСЕ | ОПП | ЕВ | ЕН | КИ | Н.расх
Я | | | | | | | | | | Раз.п Общ.п | | Такт п.
| | 010,015,020,030 | | | 13 1 Вт 2512 0,5 Ом, 1% | | R12 | | шт. | 1 | | 1
| | 010,015,020,030 | | | 14 0,25 Вт 1206 10 Ом, 1% | | R13 | | шт. | 1 | | 1
| | 010,015,020,030 | | | 15 1 Вт 2512 0,5 Ом, 1% | | R14 | | шт. | 1 | | 1
| | 010,015,020,030 | | | 16 0,125 Вт 0805 10 кОм, 1% | | R15 | | шт. | 1 | | 1
| | 010,015,020,030 | | | 17 0,125 Вт 0805 1 кОм, 1% | | R16 | | шт. | 1 | | 1
| | 010,015,020,030 | | | 18 0,25 Вт 1206 1 кОм, 1% | | R17 | | шт. | 1 | | 1
| | 010,015,020,030 | | | 19 0,125 Вт 0805 2 кОм, 1% | | R18 | | шт. | 1 | | 1
| | 010,015,020,030 | | | 20 0,125 Вт 0805 3 кОм, 1% | | R19 | | шт. | 1 | | 1
| | 010,015,020,030 | | | 21 1 Вт 2512 0,5 Ом, 1% | | R20 | | шт. | 1 | | 1
| | 010,015,020,030 | | | 22 0,125 Вт 0805 3,9 кОм, 1% | | R21 | | шт. | 1 | | 1
| | 010,015,020,030 | | | 23 0,125 Вт 0805 100 Ом, 1% | | R22 | | шт. | 1 | | 1
| | 010,015,020,030 | | | 24 0,125 Вт 0805 1 кОм, 1% | | R23 | | шт. | 1 | | 1
| | 010,015,020,030 | | | 25 1 Вт 2512 4,3 кОм, 1% | | R24 | | шт. | 1 | | 1
| | 010,015,020,030 | | | 26 0,125 Вт 0805 11 кОм, 1% | | R25 | | шт. | 1 | | 1
КК | КОМПЛЕКТОВОЧНАЯ КАРТА

ПРИЛОЖЕНИЕ | ГОСТ 3.1123 – 84 Форма 7
Дубл
Взам
Подл | изм | лист | №докум | подпис
ь
дата | изм | лист | №докум | подпись | дата
| | Листов 4 | Лист 3

Разраб
проверил
Т. Контр
ГТПП
Н. контр
К/М | Цех | Уч | РМ | Опер | Поз | Наименование ДСЕ или материала | Обозначение ДСЕ | ОПП | ЕВ | ЕН | КИ | Н.расх
Я | | | | | | | | | | Раз.п Общ.п | | Такт п.
| | 010,015,020,030 | | | 27 0,125 Вт 0805 100 кОм, 1% | | R26 | | шт. | 1 | | 1
| | 010,015,020,030 | | | 28 0,25 Вт 1206 82 кОм, 1% | | R27 | | шт. | 1 | | 1
| | 010,015,020,030 | | | 29 0,125 Вт 0805 15 кОм, 1% | | R28 | | шт. | 1 | | 1
| | 010,015,020,030 | | | 30 0,125 Вт 0805 3 кОм, 1% | | R29 | | шт. | 1 | | 1
| | 010,015,020,030 | | | 31 1 Вт 2512 180 Ом, 1% | | R30 | | шт. | 1 | | 1
| Конденсаторы
010,015,020,030 | 32 47 мкФ X5R 25В 20% 1206 | C1 | шт. | 1 | 1
010,015,020,030 | 33 0,1мкФ X7R 25В 10% 0805 | C2 | шт. | 1 | 1
010,015,020,030 | 34 1мкФ X5R 25В 10% 0805 | C3 | шт. | 1 | 1
010,015,020,030 | 35 0,47мкФ X7R 10% 1812, 250В | C4 | шт. | 1 | 1
010,015,020,030 | 36 0,1мкФ X7R 25В 10% 0805 | C5 | шт. | 1 | 1
010,015,020,030 | 37 1мкФ X5R 25В 10% 0805 | C6 | шт. | 1 | 1
010,015,020,030 | 38 470пФ X7R 500В 10% 0805 | C7 | шт. | 1 | 1
КК | КОМПЛЕКТОВОЧНАЯ КАРТА

ПРИЛОЖЕНИЕ | ГОСТ 3.1123 – 84 Форма 7
Дубл
Взам
Подл | изм | лист | №докум | подпис
ь
дата | изм | лист | №докум | подпись | дата
| | Листов 4 | Лист 3

Разраб
проверил
Т. Контр
ГТПП
Н. контр
К/М | Цех | Уч | РМ | Опер | Поз | Наименование ДСЕ или материала | Обозначение ДСЕ | ОПП | ЕВ | ЕН | КИ | Н.расх
Я | | | | | | | | | | Раз.п Общ.п | | Такт п.
| | 010,015,020,030 | | | 39 0,01мкФ X7R 25В 10% 0805 | | C8 | | шт. | 1 | | 1
| | 010,015,020,030 | | | 40 К50-35, 47мкФ, 250В, 105°C, 20% | | C9 | | шт. | 1 | | 1
| | 010,015,020,030 | | | 41 1000пФ X5R 10В 10% 0402 | | C10 | | шт. | 1 | | 1
| | 010,015,020,030 | | | 42 0,01 мкФ 250В X7R 10% 0805 | | C11 | | шт. | 1 | | 1
| | 010,015,020,030 | | | 43 0,1мкФ X7R 25В 10% 0805 | | C12 | | шт. | 1 | | 1
| Микросхемы
010,015,020,030 | 44 IR2101PBF | DA1 | шт. | 1 | 1
010,015,020,030 | 45 TL494CD | DA2 | шт. | 1 | 1
010,015,020,030 | 46 CH224K | DD1 | шт. | 1 | 1
| Светодиоды
010,015,020,030 | 47 GNL-0603GC 0603 7-12мКд 120° | HL1 | шт. | 1 | 1
КК | КОМПЛЕКТОВОЧНАЯ КАРТА

ПРИЛОЖЕНИЕ | ГОСТ 3.1123 – 84 Форма 7
Дубл
Взам
Подл | изм | лист | №докум | подпис
ь
дата | изм | лист | №докум | подпись | дата
| | Листов 4 | Лист 3

Разраб
проверил
Т. Контр
ГТПП
Н. контр
К/М | Цех | Уч | РМ | Опер | Поз | Наименование ДСЕ или материала | Обозначение ДСЕ | ОПП | ЕВ | ЕН | КИ | Н.расх
Я | | | | | | | | | | Раз.п Общ.п | | Такт п.
| | | | | Индуктивности
| | 010,015,020,030 | | | 48 CDSPRH127-221M 220мкГн 2,22А | | L1 | | шт. | 1 | | 1
| Переключатели
010,015,020,030 | 49 KLS7-TS3608-5.0-180 | SW1 | шт. | 1 | 1
| Диоды
010,015,020,030 | 50 1SMB5929B 3Вт 15В 5% | VD1 | шт. | 1 | 1
010,015,020,030 | 51 US1M 1А 1000В | VD2 | шт. | 1 | 1
010,015,020,030 | 52 US1M 1А 1000В | VD3 | шт. | 1 | 1
010,015,020,030 | 53 US1M 1А 1000В | VD4 | шт. | 1 | 1
010,015,020,030 | 54 MURS320 3А 200В | VD5 | шт. | 1 | 1
010,015,020,030 | 55 US1M 1А 1000В | VD6 | шт. | 1 | 1
010,015,020,030 | 56 MURS320 3А 200В | VD7 | шт. | 1 | 1
КК | КОМПЛЕКТОВОЧНАЯ КАРТА

ПРИЛОЖЕНИЕ | ГОСТ 3.1123 – 84 Форма 7

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

Разраб
проверил
Т. Контр
ГТПП
Н. контр
К/М | Цех | Уч | РМ | Опер | Поз | Наименование ДСЕ или материала | Обозначение ДСЕ | ОПП | ЕВ | ЕН | КИ | Н.расх
Я | | | | | | | | | | Раз.п Общ.п | | Такт п.
| | 010,015,020,030 | | | 57 US1M 1А 1000В | | VD8 | | шт. | 1 | | 1
| Транзисторы
010,015,020,030 | 58 IRFR6215TRLPBF 150В 13А 110Вт | VT1 | шт. | 1 | 1
010,015,020,030 | 59 IRF640NSTRLPBF 200В 18А 150Вт | VT2 | шт. | 1 | 1
| Разъёмы
010,015,020,030 | 60 TYPEC-304-ACP16 | X1 | шт. | 1 | 1
КК | КОМПЛЕКТОВОЧНАЯ КАРТА

ПРИЛОЖЕНИЕ - продолжение | ГОСТ 3.1123 – 84 Форма 7
Дубл
Взам
Подл | изм | лист | №докум | подпись | дата | изм | лист | №докум | подпись | дата
| | Листов 4 | Лист 4

Разраб
проверил
Т. контр
ГТПП
Н. контр
К/М | Цех | Уч | РМ | Опер | Поз | Наименование ДСЕ или материала | Обозначение ДСЕ | ОП П | ЕВ | ЕН | КИ | Н.расх
Я | | Вспомогательные материалы | | | | | | | | Раз.п Общ.п | | Такт п.
| | 010 | | | Спирто-нефрасовая смесь 1:1 | | | | кг | | | 0,0002
| | 025 | | | Спирто-нефрасовая смесь 1:1 | | | | кг | 1 | | 0,0007
| | 035 | | | Спирто-нефрасовая смесь 1:1 | | | | кг | 1 | | 0,005
| | 045 | | | Спирто-нефрасовая смесь 1:1 | | | | кг | 1 | | 0,02
| | 015 | | | Флюс ФКТ 40% | | ОСТ4ГО.033.200 | | кг | 1 | | 0,0026
| | 030 | | | Флюс ФКТ 40% | | ОСТ4ГО.033.200 | | кг | 1 | | 0,0053
| | 015 | | | Припой ПрвКР0,5 ПОС-61 | | ГОСТ21931-76 | | кг | 1 | | 0,0021
| | 030 | | | Припой ПрвКР0,5 ПОС-61 | | ГОСТ21931-76 | | кг | 1 | | 0,0042
| | 030 | | | Канифоль сосновая | | ГОСТ19113-84 | | кг | 1 | | 0,0031
| | 010 | | | Марля | | ГОСТ9412-77 | | пог. м | 1 | | 0,0003
| | 025 | | | Марля | | ГОСТ9412-77 | | пог. м | 1 | | 0,00074
| | 010 | | | Лак УР-231 | | | | кг | 1 | | 0,00012
| | 055 | | | Лак УР-231 | | | | кг | 1 | | 0,01
| | 025 | | | Краска МКЭ черная | | | | кг | 1 | | 0,0037
КК | | КОМПЛЕКТОВОЧНАЯ КАРТА

Дубл.
Взам.
Подп. | Изм | Лист № докум. | Подпись | Дата | Изм | Лист № докум. | Подпись | Дата
А | цех | Уч. | Рм | Опер. | Код, наименование операции | Обозначение документа
Б | Код, наименование оборудования | см | Проф. | Р | УТ | КР | КОИД | ЕН | ОП | К шт. | Тп.з | Т шт.
К/М | Наименование детали, сб. единицы или материала | Обозначение, код | | | | | | ОПП | ЕВ | ЕН | КИ | Н.расх.

Исполнитель должен соблюдать общие требования к монтажу
| и сборке печатных узлов, блоков, субблоков РЭА в
| соответствии с инструкцией ВШО. 045.008И. ВШО. 045.008И
| Перед началом работы необходимо выполнить требования
| По исключению влияния статического электричества на полу-
| проводниковые приборы и интегралные микросхмы в соответствии Проволока мм 0,3
| СТПВШО. 025.220-2001, ОСТ11 073.063-84, и ВШО.045.008И. ОСТ11 073.063-84
| В процессе работы исполнители должны соблюдать требования СТПВШО. 005.220-2001
| и применять защитные средства, предусмотренные инструкциями ВШО.045.008И.
| по охране труда (ИОТ)
| ИОТ №119-89 – для лакировщика РЭА
| ИОТ №129-89 – для лудильшика горячим способом
| ИОТ №120-89 – для маркировшика РЭА
МК | Маршрутная карта

Дубл.
Взам.
Подп. | Изм | Лист № докум. | Подпись | Дата | Изм | Лист № докум. | Подпись | Дата
А | цех | Уч. | Рм | Опер. | Код, наименование операции | Обозначение документа
Б | Код, наименование оборудования | см | Проф. | Р | УТ | КР | КОИД | ЕН | ОП | К шт. | Тп.з | Т шт.
К/М | Наименование детали, сб. единицы или материала | Обозначение, код | | | | | | ОПП | ЕВ | ЕН | КИ | Н.рас х.

ИОТ №130-85 – для монтажника радиоаппаратуры
ИОТ №156-88 – для контролера РЭА
ИОТ №158-89 – при хранении и обращении с диэтиленгликоль-уретаном (ДГУ), при приготовлении лака Р-231.
ИОТ №241-85 - для работающего с ЛВЖ и ГЖ.
В процессе работы отходы ЛВЖ и ГЖ сливать в специальную
тару ШМЧ.0835.00-00. После окончания работы отходы сдать
на пункт сбора в ОМТС.
005 Комплектование ВШ.30188.02433 Стол монтажниа
1. Проверить комплектность основных изделий и вспомога-ИОТ №130-85 ШНЧ.0242.0000 тельных материалов на соответствии комплектовочной карте.
МК | Маршрутная карта

Дубл.
Взам.
Подп. | Изм | Лист № докум. | Подпись | Дата | Изм | Лист № докум. | Подпись | Дата
А | цех | Уч. | Рм | Опер. | Код, наименование операции | Обозначение документа
Б | Код, наименование оборудования | см | Проф. | Р | УТ | КР | КОИД | ЕН | ОП | К шт. | Тп.з | Т шт.
К/М | Наименование детали, сб. единицы или материала | Обозначение, код | | | | | | ОПП | ЕВ | ЕН | КИ | Н.рас
х.
005 2. Проверить внешний вид электрорадиодеталей на соответствие
ТУ и наличие клейма (документа), подтверждающего их годность.
3.Улажить ЭРЭ в тару Тара Ю6372-106
010 Подготовительная ВШ.30188.02433 Стол монтажника Проверить стойкость маркировочных знаков элементов ВШ.25273.00002 ШМЧ.0242.0000 к воздействию спирто-нефрасовой смеси 1:1 (количество ИОТ №130-85 Тара для ЛВЖ -выборочно 2 шт от каждой партии) и лакировать их при ВШ7878-4023 необходимости лаком УР-231 согласно технологической Пинцет ППМ 120 инструкии ВШ.25273.00002. АРПМ6.890.001.ТУ 015 Обслуживание паяемых поверхностей выводов ЭРЭ. ВШ.30188.02433 Тампон из марли
1. Флюсовать выводы элементов поз. 02-20 ВШ.25288.00000 Кисть КФК-8 погружением в ванну с флюсом ФКТ 40% ИОТ №129-89 ГОСТ 10597-87
МК | Маршрутная карта

Дубл.
Взам.
Подп. | Изм | Лист № докум. | Подпись | Дата | Изм | Лист № докум. | Подпись | Дата
А | цех | Уч. | Рм | Опер. | Код, наименование операции | Обозначение документа
Б | Код, наименование оборудования | см | Проф. | Р | УТ | КР | КОИД | ЕН | ОП | К шт. | Тп.з | Т шт.
К/М | Наименование детали, сб. единицы или материала | Обозначение, код | | | | | | ОПП | ЕВ | ЕН | КИ | Н.рас
х.
Площадь платы 7,92 кв.дм
| 035 Элемент поз. 3 закрепить сначала клеем прокладку к плате поз.6 к эскизу.
| Крепление контровать краской МКЭ серой ОСТ4 ГО.054.180 ГОСТ 10313-78
| Сосуд с краской
БТК | 040 Контроль ВШ7850-009
| 045 Обезжирование Тампон из марли
| Обезжирить печатный узел в спиртово-нефрасовой смеси ИОТ №241-85 Кисть КМК-8
| 1:1 согласно ВШ.25000.00061 ГОСТ 10597-87
БТК | 050 Контроль Стол контролера
| 055 Лакирование ШНЧ.0242.0000
| Лакировать печатный узел лаком УР-231 и сушить Фото технология Установка
| согласно фото технологии ИОТ №119-89 ШН18.1980.00.00
| ИОТ № 158-89 ШН13.1950.00.00
| Стол лакировщика
МК | Маршрутная карта

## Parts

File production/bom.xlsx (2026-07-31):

на схеме (на плате) | Коммент | Чё это | Штук | Денег, руб. | Ссылка
X1 |  | TYPEC-304-ACP16 | 1 | 41 | https://www.ozon.ru/product/usb-c-16s-v2-5sht-razem-usb-type-c-usb-c-dlya-payki-na-platu-16-kontaktov-dlya-smartfona-1380341280/
SW1 |  | KLS7-TS3608-5.0-180 (TD-02XA), Кнопка тактовая SMD h=5мм | 1 | 8 | https://www.chipdip.ru/product/kls7-ts3608-5.0-180-td-02xa-knopka-taktovaya-smd-h-5mm-9000491323
X2 |  | WJ128-5.0-03P-14-00A, Клеммник 3-контактный, 5мм, прямой | 1 | 23 | https://www.chipdip.ru/product/wj128-5.0-03p-14-00a-klemmnik-3-kontaktnyy-5mm-wanjie-9001726974
DA2 |  | TL494CD, Импульсный регулятор напряжения [SOP-16.] | 1 | 27 | https://www.chipdip.ru/product/tl494cd-impulsnyy-regulyator-napryazheniya-sop-16-jsmicro-9001646985
DA1 |  | IR2101PBF, Драйвер MOSFET/IGBT, Half-Bridge, неинвертирующий, 0.21/0.36А, 600В [DIP-8.] | 1 | 270 | https://www.chipdip.ru/product/ir2101pbf-drayver-mosfet-igbt-half-bridge-infineon-58618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
DD1 |  | CH224K, Микросхема ESSOP10 USB Ics | 1 | 47 | https://www.chipdip.ru/product/ch224k-mikroshema-essop10-usb-ics-wch-8046185793
L1 | easy-eda взял B82477P4392M (длина и ширина больше на 0,3 мм) | CDSPRH127-221M, 220мкГн, 2.22А, 12.3х12.3х8 мм, Катушка индуктивности SMD | 1 | 55 | https://www.chipdip.ru/product/cdsprh127-221m-220mkgn-2.22a-12.3x12.3x8-mm-katushka-sce-9001493335
VT2 |  | IRF640NSTRLPBF, Транзистор N-MOSFET 200В 18А 150Вт 0.15Ом [D2PAK.] | 1 | 97 | https://www.chipdip.ru/product/irf640nstrlpbf-tranzistor-n-mosfet-200v-18a-150vt-infineon-9000578109
VT1 |  | IRFR6215TRLPBF, Транзистор P-MOSFET 150В 13А 110Вт [DPAK / TO-252.] | 1 | 140 | https://www.chipdip.ru/product/irfr6215trlpbf-tranzistor-p-mosfet-150v-13a-110vt-infineon-9000670012
VD2, VD3, VD4, VD6, VD8 (на плате D7) |  | US1M, Диод ультрабыстрый 1А 1000В [SMA / DO-214AC] | 5 | 3 | https://www.chipdip.ru/product/us1m-diod-ultrabystryy-1a-1000v-sma-do-214ac-umw-9001106096
VD1 |  | 1SMB5929B, Стабилитрон 15В 5% 3Вт [SMB] | 1 | 18 | https://www.chipdip.ru/product/1smb5929b-stabilitron-15v-5-3vt-smb-lge-9001265896
VD5, VD7 |  | MURS320, Диод ультрабыстрый 3А 200В [SMC / DO-214AB] | 2 | 11 | https://www.chipdip.ru/product/murs320-diod-ultrabystryy-3a-200v-smc-do-214ab-lge-9001655774
HL1 |  | GNL-0603GC, Светодиод зеленый SMD 0603 7-12мКд 120° 567нМ | 1 | 12 | https://www.chipdip.ru/product/gnl-0603gc-svetodiod-zelenyy-smd-0603-7-12mkd-120-g-nor-9000811934
C3, C6 |  | 1мкФ X5R 25В 10% 0805, CC0805KKX5R8BB105, Конденсатор керамический smd | 2 | 4 | https://www.chipdip.ru/product/1mkf-x5r-25v-10-0805-cc0805kkx5r8bb105-kondensator-yageo-9000181555
C2, C5, C12 |  | 0.1мкФ X7R 25В 10% 0805, CC0805KRX7R8BB104, Конденсатор керамический smd | 3 | 3 | https://www.chipdip.ru/product/0.1mkf-x7r-25v-10-0805-cc0805krx7r8bb104-kondensator-yageo-9000066545
C9 |  | К50-35, 47мкФ, 250В, 105°C, 20%, 13x25мм P:5мм, JRB2E470M05001300250000B, Конденсатор электролитический алюминиевый | 1 | 20 | https://www.chipdip.ru/product/k50-35-47mkf-250v-105-c-20-13x25mm-p-5mm-jb-capacitors-9000565877
С10 |  | 1000пФ X5R 10В 10% 0402, GRM155R61A102KA01D | 1 | 2 | https://www.chipdip.ru/product/1000pf-x5r-10v-10-0402-grm155r61a102ka01d-murata-9000121944
C8 |  | 0.01мкФ X7R 25В 10% 0805, CC0805KRX7R8BB103, Конденсатор керамический smd | 1 | 3 | https://www.chipdip.ru/product/0.01mkf-x7r-25v-10-0805-cc0805krx7r8bb103-kondensator-yageo-9000194452
C11 |  | 0.01 мкФ 250В X7R 10% 0805 (10нф), GRM21BR72E103K, Конденсатор керамический smd | 1 | 6 | https://www.chipdip.ru/product/0.01-mkf-250v-x7r-10-0805-10nf-grm21br72e103k-murata-796205664
C1 |  | 47 мкФ X5R 25В 20% 1206, GRM31CR61E476ME44L, Конденсатор керамический smd | 1 | 33 | https://www.chipdip.ru/product/47-mkf-x5r-25v-20-1206-grm31cr61e476me44l-murata-9000500396
C7 |  | 470пФ X7R 500В 10% 0805, CC0805KRX7RBBB471, Конденсатор керамический smd | 1 | 4 | https://www.chipdip.ru/product/470pf-x7r-500v-10-0805-cc0805krx7rbbb471-kondensator-yageo-9000799077
C4 |  | 0.47мкФ X7R 10% 1812, 250В, GRM43DR72E474K, Конденсатор керамический smd | 1 | 14 | https://www.chipdip.ru/product/0.47mkf-x7r-10-1812-250v-grm43dr72e474k-kondensator-murata-905758842
R9, R17 |  | 0.25Вт 1206 1 кОм, 1%, RC1206FR-071KL, Чип резистор (SMD) | 2 | 2 | https://www.chipdip.ru/product/0.25vt-1206-1-kom-rc1206fr-071kl-chip-rezistor-smd-yageo-9000412163
R1, R3, R15 |  | 0.125Вт 0805 10 кОм, 1%, RC0805FR-0710KL, Чип резистор (SMD) | 3 | 2 | https://www.chipdip.ru/product/0.125vt-0805-10-kom-1-rc0805fr-0710kl-chip-rezistor-yageo-9000272499
R2, R16, R23 |  | 0.125Вт 0805 1 кОм, 1%, AC0805FR-071KL, Чип резистор (SMD) | 3 | 2 | https://www.chipdip.ru/product/0.125vt-0805-1-kom-ac0805fr-071kl-chip-rezistor-smd-yageo-9000881292
R10 |  | 0.125Вт 0805 24 кОм, 1%, Чип резистор (SMD) | 1 | 2 | https://www.chipdip.ru/product/0.125vt-0805-24-kom-1-chip-rezistor-smd-9000079523
R28 |  | n | 1 | 2 | https://www.chipdip.ru/product/0.125vt-0805-15-kom-1-chip-rezistor-smd-9000079518
R11, R26 |  | 0.125Вт 0805 100 кОм, 1%, RC0805FR-07100KL, Чип резистор (SMD) | 2 | 2 | https://www.chipdip.ru/product/0.125vt-0805-100-kom-1-rc0805fr-07100kl-chip-rezistor-yageo-9000327566
R19, R29 |  | 0.125Вт 0805 3 кОм, 1%, Чип резистор (SMD) | 2 | 3 | https://www.chipdip.ru/product/0.125vt-0805-3-kom-1-chip-rezistor-smd-9000079497
R18 |  | 0.125Вт 0805 2 кОм, 1%, Чип резистор (SMD) | 1 | 3 | https://www.chipdip.ru/product/0.125vt-0805-2-kom-1-chip-rezistor-smd-304329612
R21 |  | 0.125Вт 0805 3.9 кОм, 1%, Чип резистор (SMD) | 1 | 2 | https://www.chipdip.ru/product/0.125vt-0805-3.9-kom-1-chip-rezistor-smd-9000079500
R22 |  | 0.125Вт 0805 100 Ом, 1%, RC0805FR-07100RL, Чип резистор (SMD) | 1 | 2 | https://www.chipdip.ru/product/0.125vt-0805-100-om-1-rc0805fr-07100rl-chip-rezistor-yageo-9000254335
R27 |  | 0.25Вт 1206 82 кОм, 1%, RC1206FR-0782KL, Чип резистор (SMD) | 1 | 2 | https://www.chipdip.ru/product/0.25vt-1206-82-kom-1-rc1206fr-0782kl-chip-rezistor-yageo-9000685440
R5 |  | 0.125Вт 0805 2.2 кОм, 1%, Чип резистор (SMD) | 1 | 2 | https://www.chipdip.ru/product/0.125vt-0805-2.2-kom-1-chip-rezistor-smd-9000079494
R12, R14, R20 |  | WSL2512R5000FEA, Резистор измерительный, SMD, 2512, 500миллиОм, 1Вт, ±1%, -60-170°C | 3 | 47 | https://www.chipdip.ru/product/wsl2512r5000fea-rezistor-izmeritelnyy-smd-2512-vishay-8041391538
R25 |  | 0.125Вт 0805 11 кОм, 1%, Чип резистор (SMD) | 1 | 2 | https://www.chipdip.ru/product/0.125vt-0805-11-kom-1-chip-rezistor-smd-9000079515
R4 |  | 0.25Вт 1206 470 Ом, 1%, Чип резистор (SMD) | 1 | 3 | https://www.chipdip.ru/product/0.25vt-1206-470-om-1-chip-rezistor-smd-9000079907
R6, R8 |  | 0.25Вт 1206 100 Ом, 1%, RC1206FR-07100RL, Чип резистор (SMD) | 2 | 2 | https://www.chipdip.ru/product/0.25vt-1206-100-om-1-rc1206fr-07100rl-chip-rezistor-yageo-9000135194
R13 |  | 0.25Вт 1206 10 Ом, 1%, RC1206FR-0710RL, Чип резистор (SMD) | 1 | 3 | https://www.chipdip.ru/product/0.25vt-1206-10-om-1-rc1206fr-0710rl-chip-rezistor-smd-yageo-9000160971
R24 |  | 1Вт 2512 4.3 кОм, 1%, RC2512FK-074K3L, Чип резистор (SMD) | 1 | 6 | https://www.chipdip.ru/product/1vt-2512-4.3-kom-1-rc2512fk-074k3l-chip-rezistor-smd-yageo-9001791819
R30 |  | 1Вт 2512 180 Ом, 1%, Чип резистор (SMD) | 1 | 11 | https://www.chipdip.ru/product/1vt-2512-180-om-1-chip-rezistor-smd-9000190105
R7 |  | 0.125Вт 0805 150 Ом, 1%, Чип резистор (SMD) | 1 | 2 | https://www.chipdip.ru/product/0.125vt-0805-150-om-1-chip-rezistor-smd-9000079466

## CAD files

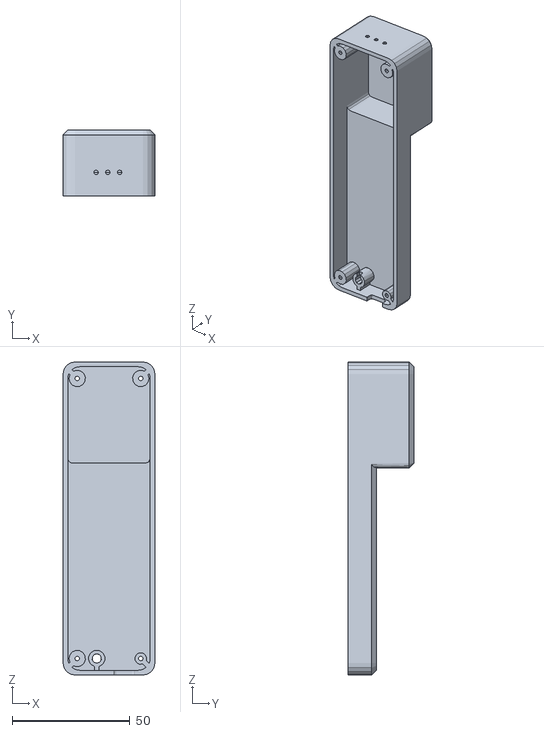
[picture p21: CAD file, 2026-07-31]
mechanical/enclosure/корпус верх.stl
39.0 x 28.0 x 133.0

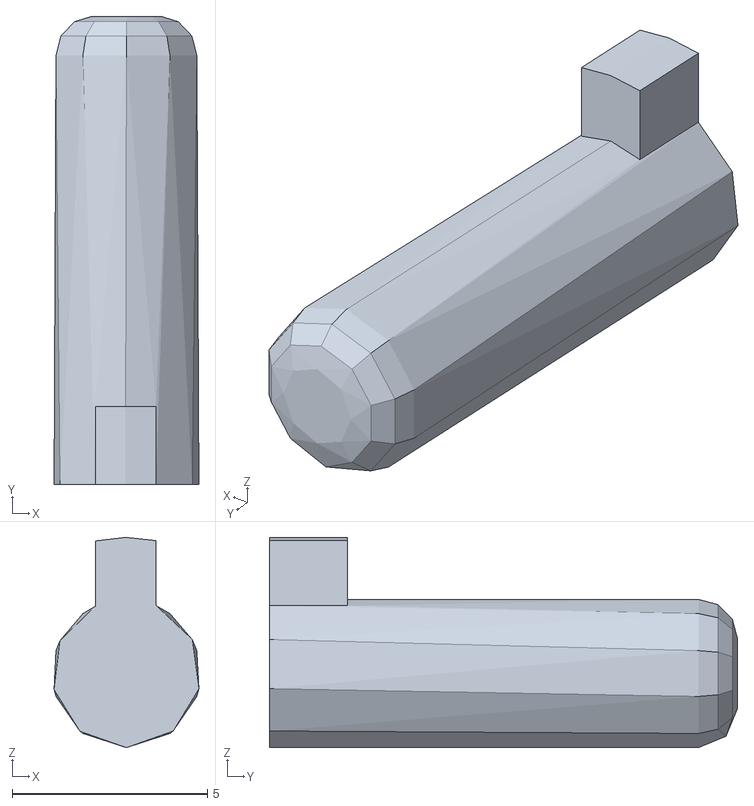
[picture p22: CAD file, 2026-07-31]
mechanical/enclosure/кнопка.stl
3.72 x 12.0 x 5.39

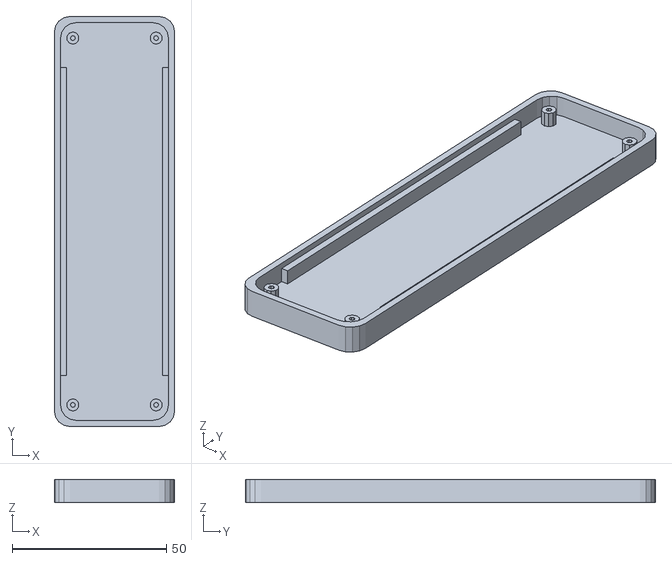
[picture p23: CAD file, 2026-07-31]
mechanical/enclosure/корпус низ.stl
39.0 x 133.0 x 7.60

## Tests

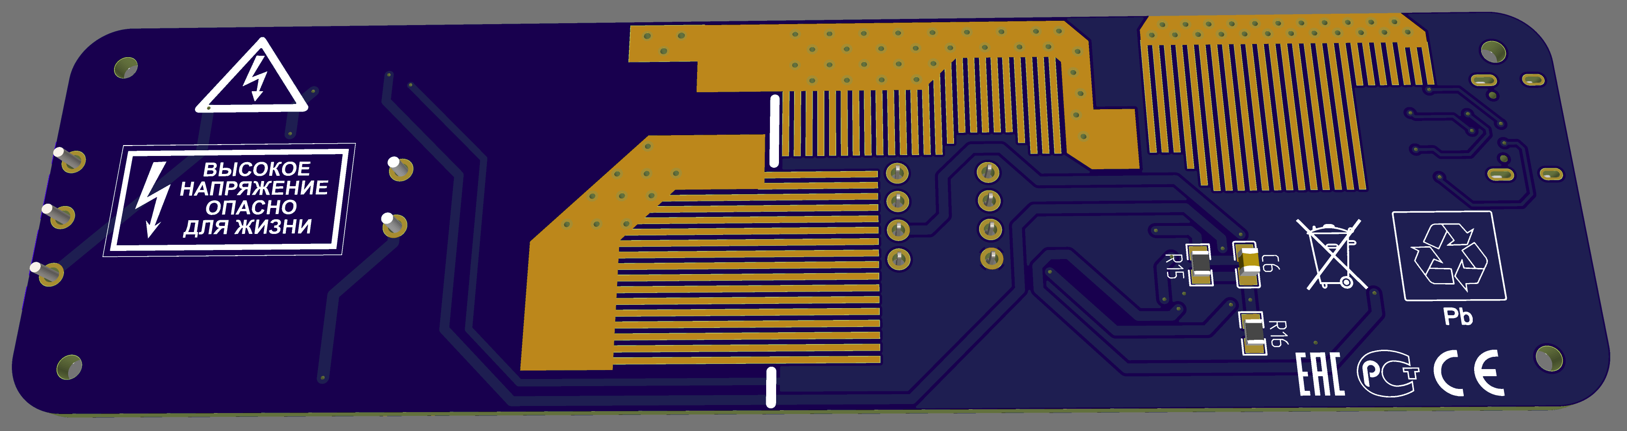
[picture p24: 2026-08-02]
electronics/easyeda/images/hv-test-stand-pcb(4).png

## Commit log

2026-07-31 Добавлена защита питания, кнопка управления и защитные цепи
    - Добавлена индикация питания и защита от скачков напряжения.
    - Добавлена кнопка включения/выключения (устройство работает только при удержании).
    - Выведены раздельные контакты для удобного подключения измерительных приборов.
    - Ограничен выходной ток для безопасной работы устройства.
    - Добавлены разрядные диоды для эне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
2026-07-31 Ограничен выходной ток и добавлены крепежные отверстия
    - Ток выходной цепи ограничен безопасным для человека уровнем (обеспечение электробезопасности).
    - Предусмотрены монтажные отверстия для надежного крепления платы.
2026-07-31 Приведение обозначений компонентов к стандартам ГОСТ
    - Наименования и обозначения компонентов на чертеже переписаны в соответствии с требованиями ГОСТ.
    - Стандартизирована спецификация элементов для корректного оформления конструкторской документации.
2026-07-31 Изменение названия
2026-07-31 Косметические изменения
    - Переходные отверстия убраны с чертежа, там они не нужны
    - Повышена читаемость наименований элементов (шелкография)
    - Дорожка в виде зиг-зага приведена в нормальный вид
2026-07-31 Убран лишний вид, изменены выноски с размерами
    - Лишний вид был убран
    - Выноски с размерами изменены из-за убранного вида
2026-07-31 Added enclosure
    [кнопка.stl, корпус верх.stl, корпус низ.stl]
2026-07-31 Add Gerber-files
    [Drill_NPTH_Through.DRL, Drill_PTH_Through.DRL, Drill_PTH_Through_Via.DRL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]
2026-07-31 1 итерация теплового расчёта
2026-07-31 2 итерация, добавлены компоненты
    - Использована полная модель печатной платы со всеми установленными компонентами.
    - Задана выборочная тепловая нагрузка на компоненты в области планарного радиатора.
    - Проведен расчет для визуализации характера распространения тепла по плате.
    - Выявлен избыточный локальный перегрев (пиковое значение 590 °C). Вероятно из-за повышенной поданной мощн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
2026-07-31 3 итерация тепловой симуляции
    - Откорректировано механическое сопряжение (тепловой контакт) радиаторов с поверхностью печатной платы для обеспечения корректной теплопередачи.
    - Добавлены скриншоты тепловых карт для проводящего рисунка платы, на которых наглядно видна теплораспределительная функция планарного радиатора.
    - Зафиксировано возрастание расчетной температуры (всл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
2026-07-31 Симуляция мягкого старта
2026-07-31 moved
    it does not matter
    [кнопка.stl, корпус верх.stl, корпус низ.stl]
2026-07-31 Пояснение работы устройства
2026-08-03 chore: compress Gerber folder into a single ZIP archive
    [Drill_NPTH_Through.DRL, Drill_PTH_Through.DRL, Drill_PTH_Through_Via.DRL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]
